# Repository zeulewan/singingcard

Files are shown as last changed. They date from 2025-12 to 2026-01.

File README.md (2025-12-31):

# KiCad Agent Experiment

An experiment to have Claude Code autonomously design and order PCBs from start to finish.

## Goal

Given project requirements (e.g., "make an ESP32 dev board with USB-C and 3 GPIO LEDs"), Claude Code should be able to:

1. Research and select appropriate components from JLCPCB's library
2. Design the schematic with proper connections
3. Create the PCB layout
4. Auto-route the traces
5. Run DRC/ERC checks
6. Generate fabrication files
7. Order the PCB via JLCPCB API

The human should only need to:
- Provide initial requirements
- Set up API keys
- Occasionally review/approve major decisions

## Status

**Setup Phase** - Installing tools and creating workflow documentation.

## Structure

```
singingcard/
├── kicad/              # KiCad project files
├── docs/               # Documentation and notes
├── venv/               # Python virtual environment
└── .claude/skills/     # Claude skill for KiCad workflow
```

## Tools

See `docs/tool-setup.md` for installed tools and configuration.

---

## Board Design

Export KiCad Images

<div align="center">
  <div>
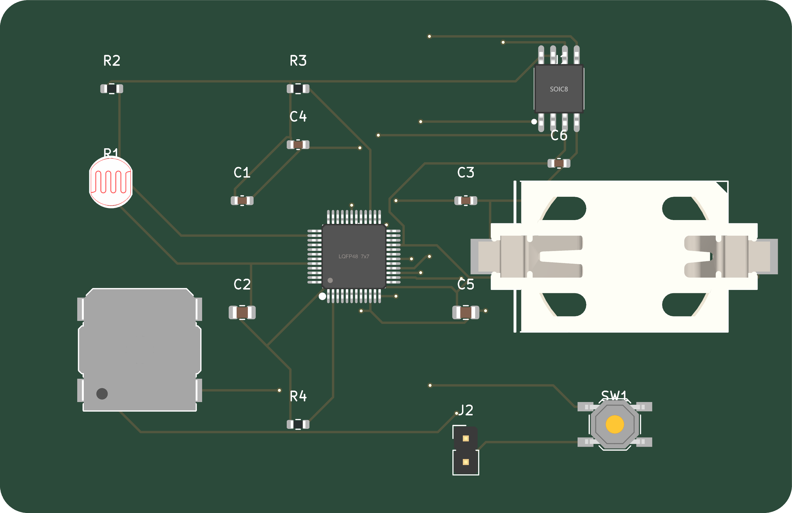
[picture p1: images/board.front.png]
3D Render Front
    
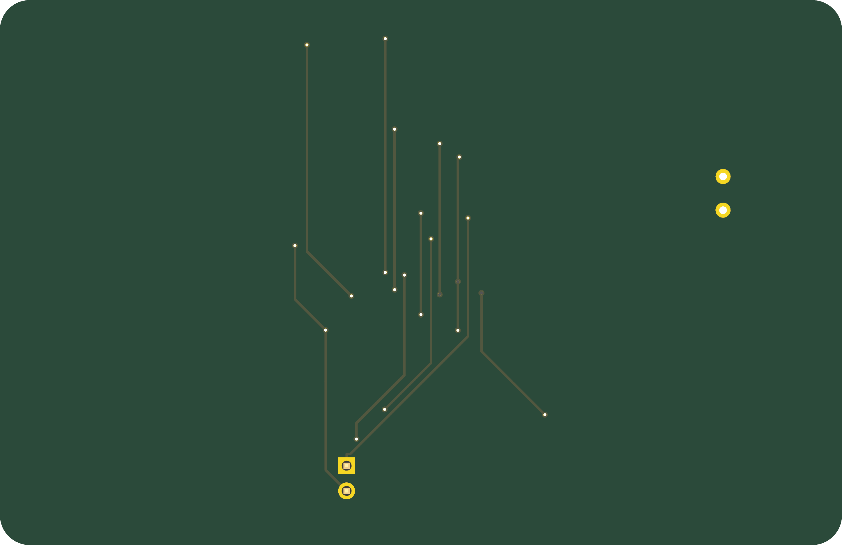
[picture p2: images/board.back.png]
3D Render Back
    
    <p><em>3D Render</em></p>
  </div>
  <br>

  <div>
    Schematic<br>
    <p><em>Schematic</em></p>
  </div>
  <br>

  <div>
    PCB Front
    PCB Back<br>
    <em>PCB Layout</em>
  </div>
</div>

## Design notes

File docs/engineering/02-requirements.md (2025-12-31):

# PCB Requirements Development

Phase 1 of PCB Systems Engineering Lifecycle.

## Activation
- User says: /pcb-requirements, develop requirements, conops
- After /pcb-init completes

## Purpose

Decompose PRD into detailed requirements and create Concept of Operations.

## Prerequisites

- `requirements/PRD.md` exists and is complete

## Process

### Step 1: Review PRD

Read `requirements/PRD.md` and extract:
- All stated requirements
- Implicit requirements (derived from use cases)
- Constraints and assumptions

### Step 2: Develop Operational Scenarios

Ask user about typical use cases:

**Question: User Profiles**
```
Who will use this device?
- End user (consumer)
- Technician (professional)
- Both
- Automated system (no direct user)
```

**Question: Primary Scenario**
```
Describe the most common way this device will be used:
1. How is it activated? (button, automatic, remote)
2. What happens during operation?
3. How long does typical operation last?
4. How is it deactivated?
```

**Question: Edge Cases**
```
What unusual situations might occur?
- Low battery
- Environmental extremes
- User errors
- Component failures
```

### Step 3: Create ConOps Document

Write `requirements/ConOps.md` with:

1. **System Overview** - One paragraph summary
2. **User Profiles** - Table of user types
3. **Operational Scenarios** - Step-by-step for each use case
4. **Operational Modes** - Normal, standby, error, etc.
5. **System States** - State machine if applicable
6. **Failure Modes** - What can go wrong, how detected

### Step 4: Decompose Requirements

Create detailed requirements in categories:

**Functional Requirements (FR-xxx)**
- What the system must DO
- Actions, behaviors, responses

**Performance Requirements (PR-xxx)**
- How WELL the system must perform
- Speed, accuracy, capacity, timing

**Interface Requirements (IR-xxx)**
- How system connects to external world
- Connectors, protocols, signals

**Environmental Requirements (ER-xxx)**
- Operating conditions
- Temperature, humidity, shock, vibration

**Physical Requirements (PHR-xxx)**
- Size, weight, form factor
- Mounting, enclosure

**Power Requirements (PWR-xxx)**
- Voltage, current, battery life
- Power states, consumption budgets

### Step 5: Assign Verification Methods

For each requirement, assign:
- **T** = Test (measure/observe in operation)
- **A** = Analysis (calculation/simulation)
- **I** = Inspection (visual examination)
- **D** = Demonstration (show it works)

### Step 6: Update RTM

Update `requirements/RTM.md` with all requirements:

```markdown
| ID | Requirement | Source | Verification | Status |
|----|-------------|--------|--------------|--------|
| FR-001 | System shall play audio | PRD 3.1 | T | Open |
| PR-001 | Audio shall be >70dB @ 10cm | PRD 4.1 | T | Open |
```

### Step 7: Output Summary

```
## Requirements Development Complete

### Statistics
- Functional Requirements: [count]
- Performance Requirements: [count]
- Interface Requirements: [count]
- Total Requirements: [count]

### Key Risks Identified
1. [risk 1]
2. [risk 2]

### Next Steps
1. Review ConOps at requirements/ConOps.md
2. Review RTM at requirements/RTM.md
3. Run /pcb-system-design to create ICD
```

## Requirement Writing Rules

Good requirements are:
- **Necessary** - Traceable to a need
- **Verifiable** - Can be tested/measured
- **Unambiguous** - Only one interpretation
- **Complete** - All conditions specified
- **Consistent** - No conflicts with other requirements
- **Atomic** - One requirement per statement

Bad: "The system should be fast"
Good: "The system shall respond within 100ms of trigger activation"

## Success Criteria

- [ ] ConOps document complete
- [ ] All requirements decomposed with IDs
- [ ] All requirements have verification method
- [ ] RTM populated
- [ ] User reviewed and approved

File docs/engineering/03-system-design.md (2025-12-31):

# PCB System Design

Phase 2 of PCB Systems Engineering Lifecycle.

## Activation
- User says: /pcb-system-design, system design, icd, block diagram
- After requirements are complete

## Purpose

Create system architecture, block diagram, and Interface Control Document.

## Prerequisites

- `requirements/PRD.md` complete
- `requirements/ConOps.md` complete
- Requirements decomposed with IDs

## Process

### Step 1: Create System Block Diagram

Identify major functional blocks from requirements:

**Common PCB Functional Blocks:**
- Power Management (input, regulation, distribution)
- Processing (MCU, DSP, FPGA)
- Memory (Flash, RAM, EEPROM)
- Sensors (analog, digital)
- Actuators (motors, speakers, LEDs)
- Communication (wired, wireless)
- User Interface (buttons, displays)
- Protection (ESD, overvoltage, reverse polarity)

**Block Diagram Elements:**
```
┌─────────────────────────────────────────────────────────┐
│                    SYSTEM BOUNDARY                       │
│                                                          │
│  ┌─────────┐     ┌─────────┐     ┌─────────┐           │
│  │  Power  │────►│   MCU   │────►│ Output  │           │
│  │ Supply  │     │         │     │         │           │
│  └─────────┘     └────┬────┘     └─────────┘           │
│                       │                                  │
│                  ┌────▼────┐                            │
│                  │ Memory  │                            │
│                  └─────────┘                            │
│                                                          │
└─────────────────────────────────────────────────────────┘
     ▲                 ▲                    │
     │                 │                    ▼
  [POWER]           [TRIGGER]           [OUTPUT]
  Battery           Button/Sensor       Speaker/LED
```

### Step 2: Define Interfaces

For each connection between blocks and external world:

**Interface Definition Table:**
| Interface ID | From | To | Type | Description |
|---|---|----|----|---|
| IF-001 | Battery | Power Supply | Power | 3V CR2032 |
| IF-002 | Power Supply | MCU | Power | 3.0V regulated |
| IF-003 | MCU | Flash | SPI | 4-wire SPI @ 10MHz |
| IF-004 | MCU | Speaker | Analog | PWM audio output |
| IF-005 | Button | MCU | Digital | Active-low input |

### Step 3: Create Interface Control Document

Write `requirements/ICD.md`:

```markdown
# Interface Control Document: [Project Name]

## Document Control
| Version | Date | Author | Changes |
|---------|------|--------|---------|
| 1.0 | [date] | [name] | Initial |

## 1. Scope
This document defines all interfaces for [Project Name].

## 2. External Interfaces

### 2.1 Power Interface (IF-001)
| Parameter | Value | Tolerance |
|-----------|-------|-----------|
| Connector | N/A (coin cell holder) | |
| Voltage | 3.0V | 2.0V - 3.3V |
| Current (peak) | [X] mA | |
| Current (avg) | [X] mA | |

### 2.2 User Interface - Trigger (IF-005)
| Parameter | Value |
|-----------|-------|
| Type | Mechanical switch / Light sensor / Pull-tab |
| Logic | Active [high/low] |
| Debounce | [X] ms in firmware |

### 2.3 Audio Output (IF-004)
| Parameter | Value |
|-----------|-------|
| Type | PWM / DAC |
| Frequency Range | [X] Hz - [Y] kHz |
| Output Level | [X] dBV |

## 3. Internal Interfaces

### 3.1 MCU to Flash Memory (IF-003)
| Signal | MCU Pin | Flash Pin | Description |
|--------|---------|-----------|-------------|
| SCK | [pin] | CLK | Clock |
| MOSI | [pin] | DI | Data In |
| MISO | [pin] | DO | Data Out |
| CS | [pin] | /CS | Chip Select |

**Protocol:** SPI Mode 0
**Clock Speed:** 10 MHz max
**Data Format:** MSB first

### 3.2 MCU to Power Supply (IF-002)
| Rail | Voltage | Current | Ripple |
|------|---------|---------|--------|
| VCC | 3.0V | [X] mA | < 50mV |

## 4. Interface Drawings
[Block diagram reference]
```

### Step 4: Allocate Requirements to Blocks

Map requirements to functional blocks:

| Requirement | Block | Notes |
|---|---|---|
| FR-001: Play audio | MCU, Flash, Speaker | Audio chain |
| FR-002: Trigger on button | MCU, Button | Input processing |
| PR-001: 5min battery life | Power, MCU | Power budget |

### Step 5: Create Budgets

**Power Budget:**
| Block | Mode | Current (mA) | Duty Cycle | Avg (mA) |
|---|---|---|---|---|
| MCU | Active | 10 | 10% | 1.0 |
| MCU | Sleep | 0.01 | 90% | 0.009 |
| Flash | Read | 15 | 5% | 0.75 |
| Flash | Standby | 0.001 | 95% | 0.001 |
| Speaker | On | 50 | 10% | 5.0 |
| **Total** | | | | **6.76** |

Battery capacity: 220mAh (CR2032)
Estimated life: 220 / 6.76 = **32.5 hours** active

**Mass Budget (if constrained):**
| Component | Mass (g) | Notes |
|---|---|---|
| PCB | 5.0 | 50x50mm FR4 |
| Battery | 3.0 | CR2032 |
| Components | 2.0 | Estimate |
| **Total** | **10.0** | |

**Cost Budget:**
| Category | Target | Allocated |
|---|---|---|
| PCB | $1.00 | |
| Components | $3.00 | |
| Assembly | $1.00 | |
| **Total** | **$5.00** | |

### Step 6: Risk Assessment

Identify technical risks:

| Risk | Probability | Impact | Mitigation |
|---|---|---|---|
| Battery life insufficient | Medium | High | Optimize sleep modes |
| Audio quality poor | Low | Medium | Use proper DAC/amp |
| Size exceeds constraint | Low | High | Component selection |

### Step 7: Prepare for SRR

Create SRR package `process/reviews/SRR.md`:

```markdown
# System Requirements Review

## Project: [Name]
## Date: [date]

## Review Items

### 1. Requirements Completeness
- [ ] All stakeholder needs captured in PRD
- [ ] All requirements have unique IDs
- [ ] All requirements are verifiable
- [ ] No conflicting requirements

### 2. ConOps Validation
- [ ] All operational scenarios documented
- [ ] Failure modes identified
- [ ] User profiles defined

### 3. Interface Definition
- [ ] All external interfaces defined
- [ ] All internal interfaces defined
- [ ] Signal levels and protocols specified

### 4. Budget Allocations
- [ ] Power budget complete
- [ ] Mass budget complete (if applicable)
- [ ] Cost budget complete

### 5. Risk Assessment
- [ ] Technical risks identified
- [ ] Mitigations defined

## Action Items
| # | Action | Owner | Due |
|---|--------|-------|-----|
| | | | |

## Decision
[ ] APPROVED - Proceed to component selection
[ ] CONDITIONAL - Complete actions first
[ ] NOT APPROVED - Major rework required

## Signatures
- Technical Lead: _________________ Date: _____
- Stakeholder: _________________ Date: _____
```

## Output Summary

```
## System Design Complete

### Deliverables
- System block diagram
- Interface Control Document (ICD.md)
- Power/Mass/Cost budgets
- Requirements allocation
- Risk register

### SRR Status
Ready for System Requirements Review

### Next Steps
1. Conduct SRR with stakeholder
2. Get approval to proceed
3. Run /pcb-components for component selection
```

## Success Criteria

- [ ] Block diagram created
- [ ] All interfaces defined in ICD
- [ ] Requirements allocated to blocks
- [ ] Budgets established
- [ ] Risks documented
- [ ] SRR package ready

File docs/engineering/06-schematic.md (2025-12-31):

# PCB Schematic Design

Phase 5 of PCB Systems Engineering Lifecycle.

## Activation
- User says: /pcb-schematic, create schematic, design schematic
- After PDR gate passes

## Purpose

Create KiCad schematic from component selection and requirements.

## Prerequisites

- PDR complete (component selection approved)
- BOM draft exists
- Datasheets available for key components

## Process

### Step 1: Gather Design Information

From datasheets, extract for each IC:
- Typical application circuit
- Required external components (caps, resistors)
- Power supply requirements
- Pin connections

### Step 2: Create/Verify Symbols

For each component:

**If symbol exists in KiCad library:**
- Verify pin count matches datasheet
- Verify pin names match datasheet
- Verify pin types (power, input, output, bidirectional)

**If custom symbol needed:**
Create using Python script or KiCad:

```python
# Symbol creation pattern
symbol = {
    'name': 'PART_NUMBER',
    'pins': [
        {'num': '1', 'name': 'VCC', 'type': 'power_in'},
        {'num': '2', 'name': 'GND', 'type': 'power_in'},
        # ... all pins from datasheet
    ]
}
```

Save to `kicad/libs/[project].kicad_sym`

### Step 3: Schematic Organization

Use hierarchical sheets for complex designs:

```
Main Sheet
├── Power Supply
├── Microcontroller
├── Audio Section
├── User Interface
└── Connectors
```

For simple designs (< 20 components), single sheet is fine.

### Step 4: Place Components

**Order of placement:**
1. Main IC (center of functional block)
2. Power input/output
3. Decoupling capacitors (near power pins)
4. External components (per application circuit)
5. Connectors

**Placement rules:**
- Group related components
- Signal flow left-to-right or top-to-bottom
- Keep power and ground clear
- Leave room for labels

### Step 5: Wire Connections

**Connection methods:**
1. **Direct wires** - For short, local connections
2. **Net labels** - For connections across the sheet
3. **Global labels** - For connections between sheets
4. **Power symbols** - For power rails (VCC, GND, +3V3)

**Net naming conventions:**
- Power rails: `+3V3`, `+5V`, `GND`, `VBAT`
- SPI: `SPI_MOSI`, `SPI_MISO`, `SPI_SCK`, `SPI_CS`
- I2C: `I2C_SDA`, `I2C_SCL`
- Audio: `AUDIO_OUT`, `SP+`, `SP-`
- General: `TRIGGER`, `STATUS_LED`

### Step 6: Add Required Elements

- [ ] Power input protection (TVS, polyfuse if needed)
- [ ] Decoupling capacitors (100nF per power pin, 10uF bulk)
- [ ] Pull-up/pull-down resistors where needed
- [ ] Test points for debugging
- [ ] Mounting holes (mechanical symbols)
- [ ] Fiducials (if needed for assembly)

### Step 7: Annotation

Run annotation to assign reference designators:
- Resistors: R1, R2, R3...
- Capacitors: C1, C2, C3...
- ICs: U1, U2...
- Connectors: J1, J2...
- Switches: SW1, SW2...
- LEDs: D1, D2... or LED1, LED2...
- Speakers: LS1, LS2...

### Step 8: Electrical Rules Check (ERC)

Run ERC and resolve all errors:

**Common ERC errors and fixes:**

| Error | Cause | Fix |
|---|---|-----|
| Unconnected pin | Pin not wired | Connect or mark "no connect" |
| Power pin not driven | No power source | Add power symbol |
| Conflicting outputs | Two outputs connected | Check design, add buffer |
| Input not driven | Floating input | Add pull-up/down or connect |

**Acceptable warnings:**
- Power flags on power input connectors
- Bidirectional pins connected to each other

### Step 9: Design Review Checklist

```markdown
### Schematic Review Checklist

**Power:**
- [ ] All power pins connected to appropriate rail
- [ ] Decoupling caps on every IC power pin
- [ ] Bulk capacitor at power input
- [ ] Power-on sequence correct (if multiple rails)

**Signals:**
- [ ] All signals have defined logic levels
- [ ] Pull-ups on open-drain outputs
- [ ] Series resistors on high-speed lines if needed
- [ ] ESD protection on external connections

**Mechanical:**
- [ ] Mounting holes included
- [ ] Connector pinouts match external devices
- [ ] Test points accessible

**Documentation:**
- [ ] All components have values
- [ ] All nets have meaningful names
- [ ] Title block filled in
- [ ] Revision number set
```

### Step 10: Export and Document

1. Export PDF: `kicad/output/[project]_schematic.pdf`
2. Export netlist for PCB
3. Save ERC report

### Step 11: Output Summary

```
## Schematic Design Complete

### Statistics
- Components: [count]
- Nets: [count]
- Sheets: [count]

### ERC Results
- Errors: 0
- Warnings: [count] (all reviewed)

### Files Created
- kicad/[project].kicad_sch
- kicad/output/[project]_schematic.pdf

### Next Steps
1. Review schematic PDF
2. Verify against datasheets
3. Run /pcb-layout to start PCB design
```

## KiCad Global Label Orientation Rules

**CRITICAL: Label orientation depends on `justify` property, not angle:**

| Wire Direction | Angle | Justify | Result |
|---|---|---|---|
| Left (←) | 180 | right | Text reads left-to-right |
| Right (→) | 0 | left | Text reads left-to-right |
| Up (↑) | 270 | left | Text reads bottom-to-top |
| Down (↓) | 90 | right | Text reads top-to-bottom |

**Rule:** Labels pointing left or down use `justify right`, others use `justify left`

## Common Application Circuits

### LDO Regulator (e.g., AMS1117)
```
VIN ─┬─[C1 10uF]─┬─ GND
     │           │
     └─[LDO]─────┴─ VOUT ─┬─[C2 10uF]─ GND
         │                 │
        GND               LOAD
```

### Flash Memory (SPI)
```
MCU                    FLASH
MOSI ──────────────── DI
MISO ──────────────── DO
SCK  ──────────────── CLK
CS   ──────────────── /CS
3V3  ──────┬───────── VCC, /WP, /HOLD
           └─[100nF]─ GND
```

### Audio Output
```
DAC_OUT ─[C 10uF]─┬─ SP+
                  │
                 [SPEAKER]
                  │
                  └─ SP- ─ GND (or diff output)
```

## Success Criteria

- [ ] All components placed and wired
- [ ] ERC passes with 0 errors
- [ ] All warnings reviewed and acceptable
- [ ] Schematic PDF exported
- [ ] Design matches datasheets
- [ ] User approved

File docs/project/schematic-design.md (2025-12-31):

# Schematic Design: Singing Birthday Card

## Block Diagram

```
                    +3V (CR2032)
                         │
                         ▼
┌─────────────────────────────────────────────────────────────┐
│                      ISD3900FYI                              │
│                                                              │
│  SPI Flash Interface          │    Speaker Output            │
│  ─────────────────            │    ─────────────             │
│  MOSI (pin 16) ◄──────────────┼──► W25Q16 DI (pin 5)        │
│  MISO (pin 13) ◄──────────────┼──► W25Q16 DO (pin 2)        │  SPK+ (pin 18) ──►┌────────┐
│  SCLK (pin 14) ◄──────────────┼──► W25Q16 CLK (pin 6)       │                    │ Speaker │
│  SSB  (pin 15) ◄──────────────┼──► W25Q16 /CS (pin 1)       │  SPK- (pin 20) ──►│  8Ω    │
│                               │                              │                    └────────┘
│  GPIO (Triggers)              │                              │
│  ─────────────────            │                              │
│  GPIO0 (pin 38) ◄────────────[R]── LDR (GL5528)             │
│  GPIO1 (pin 32) ◄────────────[SW]── Button (optional)        │
│  GPIO2 (pin 31) ◄────────────[J]── Pull-tab (optional)       │
│                               │                              │
│  Power                        │                              │
│  ─────                        │                              │
│  VCC  (pin 11) ◄──────────────┼── +3V                        │
│  VREG (pin 12) ── 1µF ── GND  │                              │
│  VSS  (pin 10) ◄──────────────┼── GND                        │
│  VCCA (pin 43) ◄──────────────┼── +3V (with 0.1µF to GND)    │
│  VSSA (pin 44) ◄──────────────┼── GND                        │
│                               │                              │
│  Clock (Internal oscillator used - no external crystal)      │
│  XTALIN (pin 36) ── NC or GND │                              │
│  XTALOUT (pin 35) ── NC       │                              │
│                               │                              │
└─────────────────────────────────────────────────────────────┘
```

## Pin Connections

### ISD3900FYI (U1) - 48-LQFP

| Pin | Name | Connection | Notes |
|-----|---|---|---|
| 1 | NC | - | |
| 2 | CSB | Pull-up 10k to VCC | SPI chip select (active low) |
| 3 | DI | SPI data in from MCU | Not used (playback only) |
| 4-7 | I2S/GPIO4-7 | NC | I2S not used |
| 8-9 | NC | - | |
| 10 | VSS | GND | Digital ground |
| 11 | VCC | +3V | Digital power |
| 12 | VREG | 1µF to GND | Internal regulator output |
| 13 | MISO | W25Q16 DO (pin 2) | Flash data out |
| 14 | SCLK | W25Q16 CLK (pin 6) | Flash clock |
| 15 | SSB | W25Q16 /CS (pin 1) | Flash chip select |
| 16 | MOSI | W25Q16 DI (pin 5) | Flash data in |
| 17 | VCCD_PWM | +3V | PWM power |
| 18 | SPK+ | Speaker + | Speaker output |
| 19 | VSSD_PWM | GND | PWM ground |
| 20 | SPK- | Speaker - | Speaker output |
| 21 | VCCD_PWM | +3V | PWM power (tied to pin 17) |
| 22-24 | NC | - | |
| 25 | INTB | NC or pull-up | Interrupt output |
| 26 | RDY/BSYB | NC or pull-up | Ready/busy output |
| 27 | RESET | Pull-up 10k to VCC | Active low reset |
| 28 | DO | NC | SPI data out (not used) |
| 29 | CLK | NC | SPI clock in (not used) |
| 30-32 | GPIO3-1 | Trigger inputs | GPIO1/2 for button/pull-tab |
| 33-34 | NC | - | |
| 35 | XTALOUT | NC | Using internal oscillator |
| 36 | XTALIN | NC or 80k to GND | Internal oscillator |
| 37 | NC | - | |
| 38 | GPIO0 | LDR voltage divider | Light sensor input |
| 39-40 | NC | - | |
| 41 | AUDOUT | NC | Line out (not used) |
| 42 | AUXOUT | NC | Aux out (not used) |
| 43 | VCCA | +3V (0.1µF to GND) | Analog power |
| 44 | VSSA | GND | Analog ground |
| 45 | ANAOUT/MIC- | NC | Not used |
| 46 | ANAIN/MIC+ | NC | Not used |
| 47 | AUXIN | NC | Not used |
| 48 | NC | - | |

### W25Q16JVSSIQ (U2) - SOIC-8

| Pin | Name | Connection |
|-----|---|---|
| 1 | /CS | ISD3900 SSB (pin 15) |
| 2 | DO | ISD3900 MISO (pin 13) |
| 3 | IO2 | Pull-up 10k to VCC (or NC) |
| 4 | GND | GND |
| 5 | DI | ISD3900 MOSI (pin 16) |
| 6 | CLK | ISD3900 SCLK (pin 14) |
| 7 | IO3 | Pull-up 10k to VCC (or NC) |
| 8 | VCC | +3V |

### CR2032 Battery Holder (B1)

| Pin | Connection |
|-----|---|
| + | +3V rail |
| - | GND |

### GL5528 LDR (R1)

Voltage divider configuration:
```
+3V ── [10k] ── GPIO0 (pin 38) ── [LDR] ── GND
```
When light hits LDR, resistance drops, voltage at GPIO0 rises.

### Speaker (LS1) - 8Ω 0.5W

| Connection | ISD3900 Pin |
|---|---|
| Speaker + | SPK+ (pin 18) |
| Speaker - | SPK- (pin 20) |

### Optional Tactile Switch (SW1)

```
GPIO1 (pin 32) ── [10k pull-up] ── +3V
           └──── [Switch] ──── GND
```

### Optional Pull-Tab Contact (J1)

```
GPIO2 (pin 31) ── [10k pull-up] ── +3V
           └──── [Tab contact] ── GND
```
When tab is inserted, contact is broken (high). When tab is pulled, contact closes (low → trigger).

## Decoupling Capacitors

| Location | Value | Notes |
|---|---|---|
| VCC (pin 11) | 0.1µF + 10µF | Close to pin |
| VREG (pin 12) | 1µF | Regulator output |
| VCCA (pin 43) | 0.1µF | Analog power |
| VCCD_PWM (pin 17,21) | 10µF | PWM power |
| W25Q16 VCC | 0.1µF | Close to pin |

## Power Budget

| Component | Current (typical) | Current (max) |
|---|---|---|
| ISD3900 (standby) | 1µA | - |
| ISD3900 (playback) | 30mA | 50mA |
| ISD3900 (speaker) | - | 150mA |
| W25Q16 (read) | 5mA | 15mA |
| **Total (playback)** | ~40mA | ~200mA |

CR2032 capacity: ~220mAh
Estimated playback time: ~5-10 hours continuous (but greeting cards are used briefly)

## Trigger Logic

The ISD3900 can be configured via SPI to trigger playback on GPIO edges:
- GPIO0: Rising edge (light detected)
- GPIO1: Falling edge (button pressed)
- GPIO2: Falling edge (tab pulled)

Jumper selection can be done by enabling/disabling the corresponding GPIO pull-ups or connections.

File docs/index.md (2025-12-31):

# PCB Engineering Process

A deterministic workflow for PCB development following NASA/DoD/IEEE systems engineering standards, adapted for small-batch manufacturing with JLCPCB.

---

## Quick Start

1. **[Engineering Process](engineering/index.md)** - Start with `00-MASTER.md`
2. Follow phases 01-10 in order
3. Complete review gates (SRR, PDR, CDR, PRR) before proceeding

---

## Documentation Structure

| Folder | Purpose |
|---|---|
| `engineering/` | Reusable process docs (phases, references) |
| `project/` | Project-specific docs (PRD, BOM, pin mapping) |

---

## Engineering Phases

| Phase | Document | Review Gate |
|---|---|---|
| 1 | [Init](engineering/01-init.md) | - |
| 2 | [Requirements](engineering/02-requirements.md) | - |
| 3 | [System Design](engineering/03-system-design.md) | **SRR** |
| 4 | [Components](engineering/04-components.md) | - |
| 5 | [Pin Allocation](engineering/05-pin-allocation.md) | **PDR** |
| 6 | [Schematic](engineering/06-schematic.md) | - |
| 7 | [Layout](engineering/07-layout.md) | **CDR** |
| 8 | [DFM](engineering/08-dfm.md) | - |
| 9 | [Manufacture](engineering/09-manufacture.md) | **PRR** |
| 10 | [Test](engineering/10-test.md) | - |

---

## Project: Singing Birthday Card

| Document | Description |
|---|---|
| [PRD](project/PRD.md) | Product requirements |
| [Component Selection](project/component-selection.md) | BOM with LCSC parts |
| [Pin Connections](project/PIN-CONNECTIONS.md) | Complete pin mapping |
| [Status](project/status.md) | Current project status |

---

## Tooling

- **KiCad 9.0.x** - EDA suite
- **kicad-cli** - Command-line automation
- **FreeRouting** - Auto-routing
- **JLCPCB** - PCB fabrication and assembly

See [KiCad Version Notes](engineering/references/KICAD-VERSION.md) for details.

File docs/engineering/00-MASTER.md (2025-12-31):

# PCB Engineering Master Process

The master orchestrator document for PCB development projects. Follow phases in order, completing review gates before proceeding.

**Standard:** NASA/DoD/IEEE systems engineering adapted for JLCPCB manufacturing.

---

## Phase Documents

| Phase | Document | Description | Gate |
|---|---|---|---|
| 1 | [`01-init.md`](01-init.md) | Project initialization, PRD | - |
| 2 | [`02-requirements.md`](02-requirements.md) | ConOps, requirements decomposition | - |
| 3 | [`03-system-design.md`](03-system-design.md) | Block diagram, ICD, budgets | **SRR** |
| 4 | [`04-components.md`](04-components.md) | JLCPCB parts research, BOM | - |
| 5 | [`05-pin-allocation.md`](05-pin-allocation.md) | Datasheet analysis, pin mapping | **PDR** |
| 6 | [`06-schematic.md`](06-schematic.md) | KiCad schematic design, ERC | - |
| 7 | [`07-layout.md`](07-layout.md) | PCB routing, DRC | **CDR** |
| 8 | [`08-dfm.md`](08-dfm.md) | Design for manufacturing review | - |
| 9 | [`09-manufacture.md`](09-manufacture.md) | Gerber export, JLCPCB order | **PRR** |
| 10 | [`10-test.md`](10-test.md) | Verification, acceptance | - |

---

## Reference Documents

| Document | Description |
|---|---|
| [`references/KICAD-VERSION.md`](references/KICAD-VERSION.md) | KiCad 9 formats, CLI commands |
| [`references/TOOLING-WISHLIST.md`](references/TOOLING-WISHLIST.md) | Desired automation tools |
| [`references/workflow-reference.md`](references/workflow-reference.md) | Quick command reference |
| [`references/tool-setup.md`](references/tool-setup.md) | Installed tools and versions |

---

## Tooling Requirements

| Tool | Version | Purpose |
|---|---|---|
| **KiCad** | 9.0.x | EDA suite (schematic, PCB, 3D) |
| **kicad-cli** | 9.0.x | Command-line automation |
| **Python** | 3.11+ | Scripting and automation |
| **FreeRouting** | 2.0.1 | Auto-routing (requires Java 21) |

**KiCad 9 Library Formats:**
- Symbols: `.kicad_sym` (single file, multiple symbols)
- Footprints: `.kicad_mod` files in `.pretty/` folders
- 3D Models: `.wrl`, `.step` in `.3dshapes/` folders

See [`references/KICAD-VERSION.md`](references/KICAD-VERSION.md) for details.

---

## 1. Lifecycle Overview

This process follows the **V-Model** approach with formal review gates. Each phase has defined entry/exit criteria, required artifacts, and a corresponding verification phase.

```
                    STAKEHOLDER NEEDS
                          │
         ┌────────────────┼────────────────┐
         │                │                │
    ┌────▼────┐      ┌────▼────┐      ┌────▼────┐
    │  PRD    │      │ ConOps  │      │  ICD    │
    │ Phase 0 │      │ Phase 1 │      │ Phase 2 │
    └────┬────┘      └────┬────┘      └────┬────┘
         │                │                │
         └────────────────┼────────────────┘
                          │
                     ▼ SRR Gate ▼
                          │
                    ┌─────▼─────┐
                    │ Component │
                    │ Selection │
                    │  Phase 3  │
                    └─────┬─────┘
                          │
                     ▼ PDR Gate ▼
                          │
              ┌───────────┴───────────┐
              │                       │
         ┌────▼────┐             ┌────▼────┐
         │Schematic│             │   PCB   │
         │ Design  │             │ Layout  │
         │ Phase 5 │             │ Phase 7 │
         └────┬────┘             └────┬────┘
              │                       │
              └───────────┬───────────┘
                          │
                     ▼ CDR Gate ▼
                          │
                    ┌─────▼─────┐
                    │    DFM    │
                    │  Review   │
                    │  Phase 8  │
                    └─────┬─────┘
                          │
                     ▼ PRR Gate ▼
                          │
                    ┌─────▼─────┐
                    │   Order   │
                    │   PCBA    │
                    │  Phase 10 │
                    └─────┬─────┘
                          │
                    ┌─────▼─────┐
                    │   Test    │
                    │ & Verify  │
                    │ Phase 11  │
                    └─────┴─────┘
```

---

## 2. Review Gates

### 2.1 System Requirements Review (SRR)
**Purpose:** Confirm all requirements are complete, consistent, and verifiable.

| Entry Criteria | Exit Criteria |
|---|---|
| PRD drafted | PRD approved by stakeholder |
| ConOps drafted | ConOps validated |
| Initial ICD drafted | Interfaces defined |
| | Requirements Traceability Matrix (RTM) started |

**Required Artifacts:**
- [ ] Product Requirements Document (PRD)
- [ ] Concept of Operations (ConOps)
- [ ] Interface Control Document (ICD)
- [ ] Mass/Power/Cost budgets (initial)
- [ ] Risk register (initial)

---

### 2.2 Preliminary Design Review (PDR)
**Purpose:** Validate component selection and preliminary architecture.

| Entry Criteria | Exit Criteria |
|---|---|
| SRR complete | All components identified |
| Component research done | JLCPCB compatibility verified |
| | Datasheets collected |
| | BOM drafted |

**Required Artifacts:**
- [ ] Component Selection Matrix
- [ ] JLCPCB Parts Library validation
- [ ] Preliminary BOM with LCSC part numbers
- [ ] Preliminary schematic block diagram
- [ ] Updated risk register

---

### 2.3 Critical Design Review (CDR)
**Purpose:** Freeze detailed design before manufacturing.

| Entry Criteria | Exit Criteria |
|---|---|
| PDR complete | Schematic complete, ERC clean |
| Schematic designed | PCB layout complete, DRC clean |
| PCB routed | All design rules met |
| | BOM finalized |

**Required Artifacts:**
- [ ] Complete schematic (PDF export)
- [ ] PCB layout (Gerber preview)
- [ ] Final BOM with all LCSC parts
- [ ] Design Rule Check report (0 errors)
- [ ] Electrical Rules Check report (0 errors)
- [ ] 3D model renders

---

### 2.4 Production Readiness Review (PRR)
**Purpose:** Confirm manufacturing files are correct and complete.

| Entry Criteria | Exit Criteria |
|---|---|
| CDR complete | Gerbers generated and verified |
| DFM review done | JLCPCB order quote reviewed |
| | Assembly files validated |

**Required Artifacts:**
- [ ] Gerber files (verified in viewer)
- [ ] Drill files
- [ ] Pick-and-place file (CPL)
- [ ] BOM in JLCPCB format
- [ ] JLCPCB order screenshot/quote

---

## 3. Phase Definitions

### Phase 0: Project Initiation
**Skill:** `/pcb-init`
**Duration:** 1 session

**Activities:**
1. Gather stakeholder needs through structured questions
2. Draft Product Requirements Document (PRD)
3. Establish project scope and constraints
4. Create project directory structure

**Questions to Ask:**
- What is the primary function of this device?
- What are the physical constraints (size, weight, enclosure)?
- What is the power source (battery type, voltage)?
- What interfaces are required (USB, I2C, SPI, etc.)?
- What is the target unit cost at volume?
- What quantity will be produced?
- What is the operating environment?
- Are there regulatory requirements (FCC, CE, UL)?

---

### Phase 1: Requirements Elicitation
**Skill:** `/pcb-requirements`
**Duration:** 1-2 sessions

**Activities:**
1. Decompose PRD into technical requirements
2. Create Concept of Operations (ConOps)
3. Define use cases and operational scenarios
4. Identify interfaces with external systems

**Deliverables:**
- ConOps document
- Functional requirements list
- Performance requirements list
- Environmental requirements list
- Interface requirements list

---

### Phase 2: System Definition
**Skill:** `/pcb-system-design`
**Duration:** 1 session

**Activities:**
1. Create system block diagram
2. Define internal interfaces (ICD)
3. Allocate requirements to subsystems
4. Establish mass/power/cost budgets

**Deliverables:**
- System block diagram
- Interface Control Document
- Requirements allocation matrix
- Budget allocations

---

### Phase 3: Component Research & Selection
**Skill:** `/pcb-components`
**Duration:** 1-3 sessions

**Activities:**
1. Research component options for each function
2. Verify JLCPCB/LCSC availability
3. Check stock levels and lead times
4. Download and analyze datasheets
5. Create component selection matrix

**JLCPCB Compatibility Checklist:**
- [ ] Part is in JLCPCB Parts Library (Basic/Extended)
- [ ] Footprint matches JLCPCB library or custom is allowed
- [ ] Stock level > order quantity + margin
- [ ] Package is SMD (for assembly) or THT marked accordingly
- [ ] Operating temperature range meets requirements

**Deliverables:**
- Component Selection Matrix
- Datasheets (saved to docs/datasheets/)
- Preliminary BOM with LCSC numbers
- Component risk assessment

---

### Phase 4: PDR Execution
**Skill:** `/pcb-pdr`
**Duration:** 1 session

**Activities:**
1. Present component selections
2. Review preliminary architecture
3. Identify remaining risks
4. Get stakeholder approval

**Deliverables:**
- PDR presentation/document
- Stakeholder sign-off
- Action items list

---

### Phase 5: Schematic Design
**Skill:** `/pcb-schematic`
**Duration:** 2-5 sessions

**Activities:**
1. Create/import component symbols
2. Place components and draw connections
3. Add power symbols and net labels
4. Run Electrical Rules Check (ERC)
5. Annotate and review

**Design Rules:**
- Use hierarchical sheets for complex designs
- Label all power rails with voltage
- Add test points for debugging
- Include decoupling capacitors per datasheet
- Add mounting holes and connectors

**Deliverables:**
- KiCad schematic (.kicad_sch)
- ERC report (0 errors, warnings reviewed)
- Schematic PDF export
- Net list

---

### Phase 6: CDR Preparation
**Skill:** `/pcb-cdr-prep`
**Duration:** 1 session

**Activities:**
1. Final schematic review
2. Preliminary PCB stackup decision
3. Critical component placement study
4. Thermal analysis (if needed)

---

### Phase 7: PCB Layout
**Skill:** `/pcb-layout`
**Duration:** 2-5 sessions

**Activities:**
1. Set board outline and mechanical constraints
2. Place components (critical first, then others)
3. Route traces (power first, then signals)
4. Add copper pours for ground/power
5. Run Design Rules Check (DRC)
6. Generate 3D model

**JLCPCB Design Rules (2-layer, 1oz copper):**
| Parameter | Minimum | Recommended |
|---|---|---|
| Trace width | 5 mil (0.127mm) | 6 mil (0.15mm) |
| Trace spacing | 5 mil (0.127mm) | 6 mil (0.15mm) |
| Via drill | 0.3mm | 0.3mm |
| Via pad | 0.6mm | 0.7mm |
| Via-to-trace | 5 mil | 6 mil |
| Hole-to-trace | 0.25mm | 0.3mm |
| Annular ring | 0.15mm | 0.2mm |

**Deliverables:**
- KiCad PCB (.kicad_pcb)
- DRC report (0 errors)
- 3D renders (front/back)
- Layer stackup document

---

### Phase 8: DFM Review
**Skill:** `/pcb-dfm`
**Duration:** 1 session

**Activities:**
1. Verify all JLCPCB design rules met
2. Check component orientations for assembly
3. Verify fiducials (if required)
4. Check silkscreen readability
5. Verify tooling holes (if panelized)

**DFM Checklist:**
- [ ] All traces meet minimum width/spacing
- [ ] All vias meet minimum drill/pad size
- [ ] Board outline is closed and on Edge.Cuts layer
- [ ] No copper-to-edge violations (<0.3mm)
- [ ] Silkscreen doesn't overlap pads
- [ ] All components have reference designators
- [ ] Fiducials present (for assembly)
- [ ] Polarity markings visible on silkscreen

---

### Phase 9: PRR Execution
**Skill:** `/pcb-prr`
**Duration:** 1 session

**Activities:**
1. Generate Gerbers using Fabrication Toolkit
2. Verify Gerbers in external viewer
3. Generate BOM and CPL files
4. Upload to JLCPCB for quote
5. Review DFM feedback from JLCPCB
6. Get stakeholder approval to order

**Deliverables:**
- Gerber ZIP file
- BOM CSV (JLCPCB format)
- CPL CSV (pick-and-place)
- JLCPCB quote screenshot
- Order confirmation

---

### Phase 10: Manufacturing
**Skill:** `/pcb-manufacture`
**Duration:** External (5-15 days)

**Activities:**
1. Submit order to JLCPCB
2. Monitor order status
3. Track shipping
4. Receive and inspect boards

**Quality Inspection Checklist:**
- [ ] Board dimensions match design
- [ ] Drill holes are correct size and location
- [ ] Copper traces are clean, no shorts/opens
- [ ] Solder mask is properly applied
- [ ] Silkscreen is readable
- [ ] Components are correctly placed
- [ ] Solder joints are acceptable
- [ ] No visible defects

---

### Phase 11: Test & Verification
**Skill:** `/pcb-test`
**Duration:** 1-3 sessions

**Activities:**
1. Visual inspection
2. Continuity testing
3. Power-on test (current limiting)
4. Functional testing per test plan
5. Document results

**Test Levels:**
1. **Unit Test:** Individual component verification
2. **Integration Test:** Subsystem interaction
3. **System Test:** Full device operation
4. **Acceptance Test:** Against requirements

**Deliverables:**
- Test report
- Verification matrix (requirements vs. test results)
- Defect log (if any)
- Lessons learned

---

## 4. Configuration Management

### 4.1 Baselines

| Baseline | Established At | Contents |
|---|---|---|
| Functional | SRR | PRD, ConOps, ICD |
| Allocated | PDR | Component list, BOM draft |
| Product | CDR | Schematic, PCB, final BOM |
| As-Built | PRR | Gerbers, manufacturing files |

### 4.2 Change Control

After each baseline is established, changes require:
1. Change request documented
2. Impact analysis performed
3. Stakeholder approval
4. Implementation and verification
5. Baseline update

### 4.3 Version Numbering

- **Documents:** `DOC-XXX_v1.0.pdf`
- **Schematics:** Revision field in title block
- **PCB:** Revision field in title block + silkscreen
- **BOM:** Version in filename `BOM_v1.0.csv`

---

## 5. Directory Structure Standard

```
project-name/
├── CLAUDE.md              # Project-specific AI instructions
├── README.md              # Project overview
├── .gitignore
│
├── docs/                  # Documentation learned
│   ├── research/          # Research notes, web findings
│   ├── datasheets/        # Component datasheets (PDF)
│   └── references/        # Standards, app notes
│
├── process/               # Systems engineering
│   ├── reviews/           # SRR, PDR, CDR, PRR documents
│   ├── baselines/         # Frozen configuration snapshots
│   └── skills/            # Phase-specific skill files
│
├── requirements/          # Requirements documents
│   ├── PRD.md             # Product Requirements Document
│   ├── ConOps.md          # Concept of Operations
│   ├── ICD.md             # Interface Control Document
│   └── RTM.md             # Requirements Traceability Matrix
│
├── kicad/                 # KiCad project files
│   ├── project.kicad_pro  # KiCad project
│   ├── project.kicad_sch  # Schematic
│   ├── project.kicad_pcb  # PCB layout
│   ├── libs/              # Custom libraries
│   │   ├── project.kicad_sym
│   │   └── project.pretty/
│   └── output/            # Generated files
│       ├── gerbers/
│       ├── bom/
│       └── images/
│
├── images/                # Auto-generated by GitHub Action
│   ├── sch.svg
│   ├── pcbf.svg
│   ├── pcbb.svg
│   └── board.step
│
├── tmp/                   # NOT TRACKED - temporary workspace
│   ├── latest_render.png  # Latest inspection image
│   └── notes.txt          # Scratch notes
│
└── firmware/              # If applicable
    └── src/
```

---

## 6. Required Documents

### 6.1 Product Requirements Document (PRD)

```markdown
# Product Requirements Document: [Project Name]

## 1. Purpose
[One paragraph describing what this product does]

## 2. Stakeholders
| Role | Name | Contact |
|------|------|---------|

## 3. Functional Requirements
| ID | Requirement | Priority | Verification |
|----|-------------|----------|--------------|
| FR-001 | | | |

## 4. Performance Requirements
| ID | Requirement | Value | Tolerance | Verification |
|----|-------------|-------|-----------|--------------|
| PR-001 | | | | |

## 5. Physical Requirements
| Parameter | Value | Notes |
|-----------|-------|-------|
| Dimensions | | |
| Weight | | |
| Enclosure | | |

## 6. Environmental Requirements
| Parameter | Min | Typ | Max |
|-----------|-----|-----|-----|
| Operating Temp | | | |
| Storage Temp | | | |
| Humidity | | | |

## 7. Power Requirements
| Parameter | Value | Notes |
|-----------|-------|-------|
| Source | | |
| Voltage | | |
| Current (avg) | | |
| Current (peak) | | |
| Battery Life | | |

## 8. Interface Requirements
| Interface | Type | Description |
|-----------|------|-------------|

## 9. Cost Targets
| Item | Target | Notes |
|------|--------|-------|
| Unit cost (1) | | |
| Unit cost (100) | | |
| Unit cost (1000) | | |

## 10. Schedule
| Milestone | Target Date |
|-----------|-------------|

## 11. Constraints
-
-

## 12. Assumptions
-
-
```

### 6.2 Concept of Operations (ConOps)

```markdown
# Concept of Operations: [Project Name]

## 1. System Overview
[Description of the system and its purpose]

## 2. User Profiles
| User Type | Description | Frequency of Use |
|-----------|-------------|------------------|

## 3. Operational Scenarios

### Scenario 1: [Name]
1. User action
2. System response
3. ...

### Scenario 2: [Name]
...

## 4. Operational Modes
| Mode | Description | Transitions |
|------|-------------|-------------|

## 5. System States
[State diagram or description]

## 6. Failure Modes
| Failure | Detection | Response |
|---------|-----------|----------|
```

### 6.3 Interface Control Document (ICD)

```markdown
# Interface Control Document: [Project Name]

## 1. External Interfaces

### 1.1 Power Interface
| Parameter | Value |
|-----------|-------|
| Connector | |
| Voltage | |
| Current | |

### 1.2 [Interface Name]
...

## 2. Internal Interfaces

### 2.1 [Subsystem A] to [Subsystem B]
| Signal | Direction | Type | Description |
|--------|-----------|------|-------------|
```

---

## 7. Skill Invocation Map

The master skill `/pcb-master` orchestrates all phases:

| Phase | Skill | Trigger Condition |
|---|---|---|
| 0 | `/pcb-init` | New project |
| 1 | `/pcb-requirements` | After PRD draft |
| 2 | `/pcb-system-design` | After ConOps |
| 3 | `/pcb-components` | After SRR |
| 4 | `/pcb-pdr` | Components selected |
| 5 | `/pcb-schematic` | After PDR |
| 6 | `/pcb-cdr-prep` | Schematic complete |
| 7 | `/pcb-layout` | After CDR prep |
| 8 | `/pcb-dfm` | Layout complete |
| 9 | `/pcb-prr` | DFM clean |
| 10 | `/pcb-manufacture` | After PRR |
| 11 | `/pcb-test` | Boards received |

---

## 8. JLCPCB Integration

### 8.1 Parts Library Categories

| Category | Description | Cost Impact |
|---|---|---|
| Basic | Standard parts, always in stock | Lowest |
| Extended | Specialty parts, usually in stock | +$3 fee |
| Consignment | Customer provides parts | Handling fee |

### 8.2 Assembly Constraints

- **Minimum component size:** 0201 (imperial)
- **Maximum component height:** 5mm (standard), 8mm (large)
- **Minimum pitch:** 0.4mm (BGA), 0.5mm (QFP)
- **Sides:** Top-only or top+bottom (extra cost)
- **Fiducials:** Required for fine-pitch (< 0.5mm)

### 8.3 File Format Requirements

**Gerbers:**
- Format: RS-274X
- Extension: Standard (e.g., `.gtl`, `.gbl`)
- Layers: F.Cu, B.Cu, F.Mask, B.Mask, F.Silkscreen, B.Silkscreen, Edge.Cuts

**Drill:**
- Format: Excellon
- Units: Metric (mm)

**BOM:**
- Format: CSV
- Columns: Designator, Footprint, Quantity, Value, LCSC Part #

**CPL:**
- Format: CSV
- Columns: Designator, Mid X, Mid Y, Rotation, Layer

---

## 9. Claude Code Limitations & Workarounds

| Limitation | Workaround |
|---|---|
| Cannot open KiCad GUI | Generate scripts, user executes in KiCad |
| Fabrication Toolkit requires GUI | User runs in KiCad, or use kicad-cli |
| Cannot view images directly | Export to tmp/, user confirms |
| DSN export not in kicad-cli | Use KiCad's Python with pcbnew module |
| FreeRouting requires Java 21 | Install via homebrew, specify path |
| Cannot upload to JLCPCB | Generate files, user uploads |

---

## 10. References

- NASA Systems Engineering Handbook (NASA/SP-2016-6105)
- NASA Procedural Requirements NPR 7123.1
- DoD Instruction 5000.88 - Engineering of Defense Systems
- IEEE 1220-2005 - Systems Engineering
- ISO/IEC/IEEE 29148:2018 - Requirements Engineering
- JLCPCB Capabilities: https://jlcpcb.com/capabilities/pcb-capabilities

---

## Appendix A: Checklists

### A.1 SRR Checklist
- [ ] PRD complete with all sections
- [ ] All requirements have unique IDs
- [ ] All requirements are verifiable
- [ ] ConOps reviewed by stakeholder
- [ ] Interfaces identified
- [ ] Risks documented

### A.2 PDR Checklist
- [ ] All functions have component selections
- [ ] All parts verified in JLCPCB library
- [ ] Datasheets downloaded and reviewed
- [ ] BOM draft with LCSC numbers
- [ ] Block diagram complete
- [ ] Risks updated

### A.3 CDR Checklist
- [ ] Schematic complete
- [ ] ERC passes with 0 errors
- [ ] PCB layout complete
- [ ] DRC passes with 0 errors
- [ ] BOM finalized
- [ ] 3D model reviewed

### A.4 PRR Checklist
- [ ] Gerbers generated
- [ ] Gerbers verified in external viewer
- [ ] BOM in JLCPCB format
- [ ] CPL in JLCPCB format
- [ ] JLCPCB quote reviewed
- [ ] Stakeholder approval obtained

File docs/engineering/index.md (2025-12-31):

# Engineering Process

Phase-based PCB development following NASA/DoD/IEEE standards.

See [00-MASTER.md](00-MASTER.md) to get started.

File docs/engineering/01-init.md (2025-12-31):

# PCB Project Initialization

Phase 0 of PCB Systems Engineering Lifecycle.

## Activation
- User says: /pcb-init, start new pcb, new pcb project, init pcb
- First phase of /pcb-master workflow

## Purpose

Gather stakeholder needs and create Product Requirements Document (PRD).

## Process

### Step 1: Project Identification

Ask the user:
```
What is the name of this project?
```

### Step 2: Structured Requirements Gathering

Use AskUserQuestion to gather requirements systematically:

**Question Set 1: Core Function**
```
What is the PRIMARY function of this device?
- Audio playback (speaker, buzzer, music)
- Sensing (temperature, light, motion, etc.)
- Control (motor, relay, LED)
- Communication (wireless, wired)
- Power management (charging, regulation)
- Other: [describe]
```

**Question Set 2: Power Source**
```
How will this device be powered?
- CR2032 coin cell (3V, ~220mAh)
- CR2025 coin cell (3V, ~160mAh)
- AAA batteries (1.5V each)
- AA batteries (1.5V each)
- LiPo battery (3.7V rechargeable)
- USB powered (5V)
- Mains powered (with transformer)
- Other: [specify]
```

**Question Set 3: Physical Constraints**
```
What are the size constraints?
- Credit card size (~85x54mm)
- Business card size (~90x55mm)
- Compact (~50x50mm or smaller)
- No constraints
- Custom: [specify dimensions]
```

**Question Set 4: Quantity & Cost**
```
What quantity will be produced?
- Prototype only (1-5 units)
- Small batch (10-50 units)
- Medium batch (100-500 units)
- Production (1000+ units)

What is the target unit cost?
- Under $5
- $5-15
- $15-50
- Over $50
- No constraint
```

**Question Set 5: Interfaces**
```
What interfaces are required? (Select all that apply)
- [ ] USB (charging or data)
- [ ] Audio output (speaker/headphones)
- [ ] Audio input (microphone)
- [ ] Display (LED, LCD, OLED)
- [ ] Buttons/switches
- [ ] Sensors (specify type)
- [ ] Wireless (WiFi, Bluetooth, LoRa)
- [ ] Programming/debug port
- [ ] Other: [specify]
```

**Question Set 6: Environment**
```
What is the operating environment?
- Indoor, room temperature only
- Indoor, wide temperature range
- Outdoor, weather protected
- Outdoor, fully exposed
- Other: [specify]
```

**Question Set 7: Special Requirements**
```
Any special requirements?
- [ ] Low power / battery life critical
- [ ] Small size critical
- [ ] Low cost critical
- [ ] Fast time to market
- [ ] Regulatory compliance (FCC, CE)
- [ ] Safety critical
- [ ] None
```

### Step 3: Create Directory Structure

```bash
mkdir -p requirements docs/{research,datasheets,references} \
         process/{reviews,baselines} kicad/{libs,output} tmp
```

### Step 4: Generate PRD

Create `requirements/PRD.md` using the template from PCB-SYSTEMS-ENGINEERING.md, filling in gathered information.

### Step 5: Output Summary

```
## Project Initialized: [Project Name]

### Key Requirements
- Function: [primary function]
- Power: [power source]
- Size: [dimensions]
- Quantity: [volume]
- Cost Target: [target]

### Next Steps
1. Review the PRD at requirements/PRD.md
2. Edit any incorrect information
3. Run /pcb-requirements to develop ConOps

### Files Created
- requirements/PRD.md
- requirements/ConOps.md (template)
- requirements/ICD.md (template)
- requirements/RTM.md (template)
```

## Templates to Create

### PRD.md Template
Fill in the template from PCB-SYSTEMS-ENGINEERING.md Section 6.1

### ConOps.md Template (Empty)
Fill in the template from PCB-SYSTEMS-ENGINEERING.md Section 6.2

### ICD.md Template (Empty)
Fill in the template from PCB-SYSTEMS-ENGINEERING.md Section 6.3

### RTM.md Template
```markdown
# Requirements Traceability Matrix

| Req ID | Requirement | Source | Allocated To | Verification | Status |
|--------|-------------|--------|--------------|--------------|--------|
| FR-001 | | PRD | | | Open |
```

## Success Criteria

- [ ] All key questions answered
- [ ] PRD created with all sections
- [ ] Directory structure in place
- [ ] User understands next steps

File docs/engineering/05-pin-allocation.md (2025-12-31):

# PCB Pin Allocation & Datasheet Analysis

Phase 3.5 of PCB Systems Engineering Lifecycle - between component selection and schematic design.

## Activation
- User says: /pcb-pin-allocation, pin allocation, datasheet analysis, chip research
- After component selection, before schematic design

## Purpose

Thoroughly analyze all component datasheets and create a complete pin connection map before starting schematic design.

## Prerequisites

- Component selection complete (BOM exists)
- LCSC/JLCPCB part numbers identified

## Critical Rules

**DO NOT start schematic design until this phase is complete.**

1. **Read EVERY datasheet** - No exceptions
2. **Understand EVERY pin** - Know what each pin does
3. **Document EVERY connection** - In PIN-CONNECTIONS.md
4. **NEVER GUESS** - Each pin function MUST come from the datasheet

**If you cannot access a datasheet, you CANNOT proceed with that component.**

KiCad symbols are NOT authoritative - they may have errors or be incomplete. The datasheet is the single source of truth.

## Process

### Step 1: Create Datasheets Directory

```bash
mkdir -p docs/datasheets
```

### Step 2: Download All Datasheets

For each component in BOM:

1. **ICs (Critical):** Download full datasheet from manufacturer
2. **Passives:** Note values, tolerances, voltage ratings
3. **Connectors:** Download mechanical drawings
4. **Specialty:** Sensors, speakers, displays - full datasheets

**Datasheet Sources:**
- LCSC product page → Datasheet link
- Manufacturer website (preferred - most current)
- Octopart/Findchips for alternatives

**Naming Convention:**
```
docs/datasheets/
├── ISD3900_datasheet.pdf
├── W25Q16JV_datasheet.pdf
├── AMS1117-3.3_datasheet.pdf
├── KLJ-01304T_speaker_datasheet.pdf
└── GL5528_LDR_datasheet.pdf
```

### Step 3: Read Each Datasheet - Extract Key Information

For each IC, document:

#### 3.1 Power Requirements
```markdown
## [Part Number] Power

| Parameter | Min | Typ | Max | Unit |
|-----------|-----|-----|-----|------|
| VCC | 2.7 | 3.0 | 3.6 | V |
| ICC (active) | - | 15 | 25 | mA |
| ICC (standby) | - | 1 | 5 | µA |

**Power Pins:**
- VCC: pins 5, 17, 28
- GND: pins 6, 18, 29
- AVCC (analog): pin 12

**Decoupling Required:**
- 100nF on each VCC/GND pair
- 10µF bulk on main supply
```

#### 3.2 Pin Functions
```markdown
## [Part Number] Pin Functions

| Pin | Name | Type | Description |
|-----|------|------|-------------|
| 1 | RESET | Input | Active low reset |
| 2 | XTAL1 | Input | Crystal input |
| 3 | XTAL2 | Output | Crystal output |
| ... | ... | ... | ... |

**Pin Types:**
- Power: VCC, GND, AVCC, AGND
- Input: Digital input, analog input
- Output: Digital output, open-drain, push-pull
- I/O: Bidirectional
- NC: No connect (leave floating or tie to GND per datasheet)
```

#### 3.3 Interface Requirements
```markdown
## [Part Number] Interfaces

### SPI Interface
| Signal | Pin | Notes |
|--------|-----|-------|
| MOSI | 15 | Master Out, Slave In |
| MISO | 16 | Master In, Slave Out |
| SCK | 17 | Clock, max 10MHz |
| CS | 18 | Active low chip select |

**SPI Mode:** Mode 0 (CPOL=0, CPHA=0)
**Max Clock:** 10 MHz
**Bit Order:** MSB first

### I2C Interface
| Signal | Pin | Notes |
|--------|-----|-------|
| SDA | 20 | Needs 4.7k pull-up |
| SCL | 21 | Needs 4.7k pull-up |

**Address:** 0x50 (7-bit)
**Max Clock:** 400 kHz
```

#### 3.4 Application Circuit
```markdown
## [Part Number] Application Circuit

From datasheet Figure X, page Y:

**Required External Components:**
- C1: 100nF ceramic, VCC to GND
- C2: 10µF electrolytic, VCC to GND
- R1: 10k pull-up on RESET
- Y1: 12MHz crystal
- C3, C4: 22pF load capacitors for crystal

**Optional Components:**
- LED on status pin (with 330R series)
- External EEPROM on I2C bus
```

#### 3.5 Absolute Maximum Ratings
```markdown
## [Part Number] Absolute Maximums

| Parameter | Value | Notes |
|-----------|-------|-------|
| VCC | 4.0V | Destroy above this |
| Input voltage | VCC + 0.5V | ESD clamp |
| Output current | 25mA | Per pin |
| Total power | 500mW | With derating |
| Storage temp | -40 to +85°C | |
```

### Step 4: Create Pin Connection Matrix

Create `docs/PIN-CONNECTIONS.md`:

```markdown
# Pin Connections

## System Overview

[Block diagram of connections]

## Net List

| Net Name | Source | Destination(s) | Notes |
|----------|--------|----------------|-------|
| +3V3 | U3.OUT | U1.VCC, U2.VCC, C1+ | Main 3.3V rail |
| GND | Battery- | All GND pins | Star ground |
| SPI_MOSI | U1.MOSI | U2.DI | SPI data out |
| SPI_MISO | U2.DO | U1.MISO | SPI data in |
| SPI_SCK | U1.SCK | U2.CLK | SPI clock |
| SPI_CS | U1.GPIO5 | U2./CS | Chip select |

## Component Pin Assignments

### U1: [Main IC]

| Pin | Name | Net | Connection | Notes |
|-----|------|-----|------------|-------|
| 1 | VCC | +3V3 | Power rail | 100nF to GND |
| 2 | GND | GND | Ground | |
| 3 | MOSI | SPI_MOSI | U2.DI | |
| 4 | MISO | SPI_MISO | U2.DO | |
| ... | ... | ... | ... | ... |

### U2: [Flash Memory]

| Pin | Name | Net | Connection | Notes |
|-----|------|-----|------------|-------|
| 1 | /CS | SPI_CS | U1.GPIO5 | Active low |
| 2 | DO | SPI_MISO | U1.MISO | |
| 3 | /WP | +3V3 | Pull high | Disable write protect |
| 4 | GND | GND | Ground | |
| 5 | DI | SPI_MOSI | U1.MOSI | |
| 6 | CLK | SPI_SCK | U1.SCK | |
| 7 | /HOLD | +3V3 | Pull high | Disable hold |
| 8 | VCC | +3V3 | Power | 100nF to GND |

### Passive Components

| Ref | Value | Net 1 | Net 2 | Purpose |
|-----|-------|-------|-------|---------|
| C1 | 100nF | +3V3 | GND | U1 decoupling |
| C2 | 100nF | +3V3 | GND | U2 decoupling |
| C3 | 10µF | +3V3 | GND | Bulk capacitor |
| R1 | 10k | TRIGGER | GND | Pull-down |

## Power Distribution

```
Battery (+3V)
    │
    ├──[Polarity Protection]──┬── VCC_RAW
    │                         │
    │                    [LDO 3.3V]
    │                         │
    │                         ├── +3V3
    │                         │    ├── U1.VCC (100nF)
    │                         │    ├── U2.VCC (100nF)
    │                         │    └── 10µF bulk
    │                         │
    └─────────────────────────┴── GND
```

## Signal Routing Priority

1. **Power:** Wide traces, short paths
2. **Clock/Crystal:** Short, away from noisy signals
3. **SPI:** Keep together, matched lengths if >10MHz
4. **Audio:** Away from digital, ground shield if possible
5. **GPIO:** Flexible routing

## Open Questions

- [ ] Does U1 need external crystal or internal oscillator OK?
- [ ] What pull-up value for I2C? (Depends on bus capacitance)
- [ ] Speaker connection: single-ended or differential?
```

### Step 5: Verify Completeness

Checklist before proceeding to schematic:

```markdown
## Pre-Schematic Checklist

### Datasheets Downloaded
- [ ] U1: [part] - datasheet.pdf
- [ ] U2: [part] - datasheet.pdf
- [ ] All ICs have datasheets

### Power Analysis
- [ ] All power pins identified
- [ ] Current budget calculated
- [ ] Decoupling requirements noted

### Pin Allocation
- [ ] All IC pins have assignments
- [ ] No pin conflicts
- [ ] All interfaces defined

### External Components
- [ ] All required passives identified
- [ ] Values match datasheet recommendations
- [ ] Voltage ratings adequate

### Questions Resolved
- [ ] All "Open Questions" answered
- [ ] Ambiguities clarified with datasheets or research
```

## Output

After completing this phase:

```
docs/
├── datasheets/
│   ├── ISD3900_datasheet.pdf
│   ├── W25Q16JV_datasheet.pdf
│   └── ...
├── PIN-CONNECTIONS.md      # Complete pin map
└── research/
    └── chip-notes.md       # Detailed notes from datasheets
```

## Datasheet Sources and Fallbacks

**Primary Sources (in order):**
1. Manufacturer website (most current, most reliable)
2. LCSC product page → Datasheet link
3. Octopart/Findchips
4. Mouser/DigiKey product pages

**Cross-Reference: KiCad Symbol Files**
After reading datasheets, verify KiCad symbols match:
- `kicad/libs/*.kicad_sym` - Compare pin names/numbers against datasheet
- Flag any discrepancies for correction

```bash
# List pin definitions from symbol file for verification
grep -A2 "pin " kicad/libs/project.kicad_sym
```

**If Datasheet Unavailable:**
- Try alternative sources (Mouser, DigiKey, Octopart)
- Contact manufacturer directly
- **DO NOT proceed with component if datasheet cannot be obtained**
- Consider selecting an alternative component with available documentation

**Web Fetch Limitations:**
- Some manufacturer sites block automated downloads
- Chinese datasheets may have encoding issues
- Large PDFs may timeout
- Solution: Have user manually download and place in `docs/datasheets/`

## Common Mistakes to Avoid

1. **Skipping datasheet reading** - "I'll figure it out in schematic" → errors
2. **Ignoring NC pins** - Some must be grounded, some must float
3. **Missing decoupling** - Every IC power pin needs capacitor
4. **Wrong pull-up/down** - Check if internal exists, correct value
5. **Voltage level mismatch** - 3.3V IC connected to 5V signal
6. **Forgetting analog ground** - AGND vs DGND separation

## Success Criteria

- [ ] All datasheets downloaded
- [ ] All datasheets read and understood
- [ ] PIN-CONNECTIONS.md complete
- [ ] All pins assigned
- [ ] No conflicts or ambiguities
- [ ] Ready for schematic design

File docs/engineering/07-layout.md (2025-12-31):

# PCB Layout Design

Phase 7 of PCB Systems Engineering Lifecycle.

## Activation
- User says: /pcb-layout, route pcb, pcb design, layout
- After schematic is complete

## Purpose

Create PCB layout from schematic with proper routing for JLCPCB manufacturing.

## Prerequisites

- Schematic complete with ERC clean
- Netlist generated
- Footprints assigned to all components

## JLCPCB Design Rules

### 2-Layer Board (1oz Copper) - Standard

| Parameter | Minimum | Recommended |
|---|---|---|
| Trace width | 0.127mm (5mil) | 0.15mm (6mil) |
| Trace spacing | 0.127mm (5mil) | 0.15mm (6mil) |
| Via drill | 0.3mm | 0.3mm |
| Via pad | 0.6mm | 0.7mm |
| Via-to-trace | 0.127mm (5mil) | 0.15mm (6mil) |
| Hole-to-trace | 0.25mm | 0.3mm |
| Hole-to-hole | 0.25mm | 0.3mm |
| Annular ring | 0.15mm | 0.2mm |
| Copper-to-edge | 0.3mm | 0.5mm |
| Silkscreen width | 0.15mm | 0.2mm |
| Silkscreen height | 0.8mm | 1.0mm |

### 4-Layer Board (1oz Copper)

| Parameter | Minimum | Recommended |
|---|---|---|
| Trace width | 0.09mm (3.5mil) | 0.1mm (4mil) |
| Trace spacing | 0.09mm (3.5mil) | 0.1mm (4mil) |
| Via drill | 0.2mm | 0.25mm |
| Via pad | 0.45mm | 0.5mm |

## Process

### Step 1: Board Setup

1. **Set board outline:**
   - Draw on Edge.Cuts layer
   - Closed polygon required
   - Consider mounting holes in corners
   - Consider enclosure fit

2. **Set design rules:**
   - File → Board Setup → Design Rules
   - Set clearance, track width, via size per JLCPCB specs
   - Add net classes for power (wider traces)

3. **Set stackup (if multilayer):**
   - File → Board Setup → Board Stackup
   - Standard 4-layer: Sig-GND-VCC-Sig

### Step 2: Component Placement

**Placement order:**
1. **Fixed items first:**
   - Connectors (USB, headers)
   - Mounting holes
   - Components with mechanical constraints

2. **Critical components:**
   - Main IC
   - Crystal/oscillator near IC
   - Decoupling caps near power pins

3. **Thermal considerations:**
   - High-power components away from edges
   - Heat-generating parts with clearance

4. **Signal flow:**
   - Input on one side, output on other
   - Minimize trace lengths

**Placement rules:**
- Keep related components close
- Align components in grid pattern
- Orient ICs consistently (pin 1 direction)
- Ensure reference designators visible
- Leave room for routing

### Step 3: Power Distribution

1. **Power planes or pours:**
   - 4-layer: Use internal layers for VCC/GND
   - 2-layer: Use copper pours on both layers

2. **Power trace sizing:**
   - Use net classes for power rails
   - Calculate trace width for current:
     - 1A @ 1oz: ~0.5mm trace (internal), ~0.3mm (external)
     - See IPC-2221 calculator

3. **Ground strategy:**
   - Single ground plane preferred
   - Star ground for analog/digital split
   - Avoid ground loops

### Step 4: Signal Routing

**Routing priority:**
1. Critical signals (clocks, high-speed)
2. Analog signals
3. Digital signals
4. Power connections

**Routing rules:**
- Avoid 90° angles (use 45° or curves)
- Match lengths for differential pairs
- Keep analog away from digital
- Cross signals at 90° on different layers
- Use vias to switch layers

**Routing strategies:**
- **Interactive routing:** Manual, highest control
- **Push-and-shove:** KiCad's smart routing
- **Autorouter:** FreeRouting for assistance

### Step 5: Autorouting (Optional)

**Using FreeRouting:**

1. Export DSN from KiCad:
```python
# Via KiCad Python console
import pcbnew
board = pcbnew.LoadBoard("project.kicad_pcb")
pcbnew.ExportSpecctraDSN(board, "project.dsn")
```

2. Run FreeRouting:
```bash
/opt/homebrew/opt/openjdk@21/bin/java -jar freerouting.jar
```

3. Import SES back:
```python
pcbnew.ImportSpecctraSES(board, "project.ses")
pcbnew.SaveBoard("project.kicad_pcb", board)
```

**Note:** Manual cleanup usually required after autorouting.

### Step 6: Copper Pours

1. **Add ground pour:**
   - Select both layers for 2-layer
   - Set net to GND
   - Set clearance per design rules
   - Use solid fill (not hatched)

2. **Add power pour (if needed):**
   - Typically smaller area
   - Connect to power traces

3. **Fill zones:**
   - Edit → Fill All Zones (B)
   - Check for isolated copper islands
   - Remove islands or add stitching vias

### Step 7: Silkscreen

- [ ] Reference designators visible and not overlapping pads
- [ ] Pin 1/polarity markings visible
- [ ] Board name and revision
- [ ] Date or version indicator
- [ ] Company/project logo (optional)
- [ ] Important warnings (ESD, polarity)

### Step 8: Design Rules Check (DRC)

Run DRC and fix all errors:

| Error | Cause | Fix |
|---|---|-----|
| Clearance violation | Traces too close | Reroute with more space |
| Track too thin | Below minimum | Widen trace |
| Unconnected net | Missing connection | Route or via |
| Annular ring too small | Via too small | Increase pad size |
| Copper-to-edge | Too close to board edge | Move copper in |

**DRC must show 0 errors before proceeding.**

### Step 9: 3D Model Review

1. View 3D model: View → 3D Viewer
2. Check:
   - [ ] Components fit without overlap
   - [ ] Correct component heights
   - [ ] Connectors accessible
   - [ ] Mounting holes clear
3. Export renders to `tmp/` for inspection

### Step 10: Output Summary

```
## PCB Layout Complete

### Board Statistics
- Size: [X] x [Y] mm
- Layers: [count]
- Components: [count]
- Vias: [count]
- Traces: [length]

### DRC Results
- Errors: 0
- Warnings: [count] (all reviewed)
- Unconnected nets: 0

### Files Updated
- kicad/[project].kicad_pcb

### Next Steps
1. Review 3D model in tmp/
2. Run /pcb-dfm for manufacturing check
```

## Layer Usage (2-Layer)

| Layer | Purpose |
|---|---|
| F.Cu | Top copper - most routing |
| B.Cu | Bottom copper - ground pour, some routing |
| F.Silkscreen | Top silkscreen - designators, labels |
| B.Silkscreen | Bottom silkscreen - if needed |
| F.Mask | Top solder mask (auto) |
| B.Mask | Bottom solder mask (auto) |
| F.Paste | Top solder paste (auto) |
| B.Paste | Bottom solder paste (auto) |
| Edge.Cuts | Board outline |
| F.Courtyard | Component keepout |
| F.Fab | Fabrication notes |

## Common Mistakes

1. **Forgetting decoupling caps near IC**
   - Place 100nF within 3mm of power pins

2. **Traces too close to edge**
   - Minimum 0.3mm, prefer 0.5mm

3. **Silkscreen on pads**
   - Enable "Subtract soldermask from silkscreen"

4. **Floating copper**
   - Connect or remove isolated copper islands

5. **Via under component**
   - Avoid unless needed for thermal

## Success Criteria

- [ ] All nets routed (0 unconnected)
- [ ] DRC passes with 0 errors
- [ ] 3D model reviewed
- [ ] Component placement verified
- [ ] Silkscreen readable
- [ ] Ground pour complete

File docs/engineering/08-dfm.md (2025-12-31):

# PCB Design for Manufacturing Review

Phase 8 of PCB Systems Engineering Lifecycle.

## Activation
- User says: /pcb-dfm, dfm check, manufacturing review
- After PCB layout complete

## Purpose

Verify PCB design meets JLCPCB manufacturing requirements before generating production files.

## Prerequisites

- PCB layout complete
- DRC passes with 0 errors
- 3D model reviewed

## DFM Checklist

### 1. Board Dimensions

- [ ] Board outline is closed polygon on Edge.Cuts
- [ ] Minimum size: 5mm x 5mm
- [ ] Maximum size: 400mm x 500mm
- [ ] No internal cutouts violate minimum rules
- [ ] Corners have appropriate radius (if required)

### 2. Copper Layers

**Trace Width & Spacing:**

| Copper | Min Width | Min Spacing | Status |
|---|---|---|---|
| 1oz external | 5mil (0.127mm) | 5mil (0.127mm) | [ ] |
| 1oz internal | 3.5mil (0.09mm) | 3.5mil (0.09mm) | [ ] |
| 2oz external | 8mil (0.2mm) | 8mil (0.2mm) | [ ] |

**Copper Pour:**
- [ ] No isolated copper islands (or intentionally left)
- [ ] Thermal relief on pads (not direct connect unless intended)
- [ ] Pour clearance meets minimum spacing

**Copper-to-Edge:**
- [ ] Minimum 0.3mm from copper to board edge
- [ ] V-score lines have appropriate copper clearance

### 3. Drill/Via

| Parameter | Min Value | Design Value | Status |
|---|---|---|---|
| Via drill (2L) | 0.3mm | | [ ] |
| Via drill (4L+) | 0.2mm | | [ ] |
| Via pad (2L) | 0.6mm | | [ ] |
| Via pad (4L+) | 0.45mm | | [ ] |
| PTH drill min | 0.15mm | | [ ] |
| PTH drill max | 6.3mm | | [ ] |
| NPTH drill min | 0.5mm | | [ ] |
| Hole-to-hole | 0.25mm | | [ ] |
| Hole-to-trace | 0.25mm | | [ ] |

**Via Tenting:**
- [ ] Decide: tented (covered by solder mask) or open
- [ ] Tented vias reduce risk of shorts from solder

### 4. Solder Mask

- [ ] Solder mask expansion appropriate (typically 0.05mm)
- [ ] No mask slivers (thin strips between pads)
- [ ] Mask bridge between fine-pitch pads (check 0.5mm pitch and below)
- [ ] Mask color selected (green fastest/cheapest)

### 5. Silkscreen

- [ ] Minimum line width: 0.15mm (0.2mm preferred)
- [ ] Minimum text height: 0.8mm (1.0mm preferred)
- [ ] No silkscreen on pads
- [ ] No silkscreen on exposed copper
- [ ] Reference designators readable
- [ ] Polarity markings present for polarized components
- [ ] Pin 1 indicators visible

**Silkscreen Conflicts:**
- Enable "Subtract soldermask from silkscreen" in plot settings
- Or manually adjust silkscreen graphics

### 6. Component Placement (for Assembly)

**Orientation:**
- [ ] All components on designated side(s)
- [ ] Consistent IC orientation (pin 1 direction)
- [ ] Components accessible for rework

**Spacing:**
- [ ] Minimum component-to-component spacing met
- [ ] Minimum component-to-edge spacing met
- [ ] Tall components don't shadow shorter ones

**Fiducials (for fine-pitch assembly):**
- [ ] Fiducials present if using 0.5mm pitch or finer
- [ ] Minimum 3 fiducials (recommended: 4 corners + near fine-pitch)
- [ ] Fiducial size: 1mm pad with 2mm clearance

### 7. Special Features

**Slots:**
- [ ] Minimum slot width: 0.65mm (metallized), 1.0mm (non-metallized)
- [ ] Slot length ≥ 2x width (ideally 2.5x)

**Edge Plating:**
- [ ] If needed, properly specified

**Castellated Holes:**
- [ ] If needed, minimum half-hole size 0.6mm

### 8. Layer Alignment

- [ ] All layers use same origin
- [ ] Drill file origin matches Gerber origin
- [ ] Outline on Edge.Cuts layer only

## DFM Review Process

### Step 1: Run Final DRC

Verify 0 errors:
```
Inspect → Design Rules Checker
```

### Step 2: Check Clearances

Use KiCad's clearance measurement:
```
Inspect → Measure (Ctrl+M)
```

Verify:
- Trace-to-trace clearance
- Trace-to-via clearance
- Trace-to-edge clearance

### Step 3: Review Layer by Layer

View each layer independently:
1. F.Cu - Check routing, pours
2. B.Cu - Check routing, ground pour
3. F.Silkscreen - Check readability
4. B.Silkscreen - Check if needed
5. F.Mask - Check pad exposure
6. Edge.Cuts - Check outline is closed

### Step 4: 3D Model Final Check

- [ ] All components present
- [ ] No component collisions
- [ ] Mounting holes clear
- [ ] Connectors accessible
- [ ] Board fits intended enclosure

### Step 5: Generate Test Gerbers

Generate preliminary Gerbers for review:
```bash
kicad-cli pcb export gerbers --layers F.Cu,B.Cu,F.Mask,B.Mask,F.Silkscreen,Edge.Cuts project.kicad_pcb
```

### Step 6: View in External Gerber Viewer

Use one of:
- gerbv (open source)
- Online viewer at JLCPCB
- KiCad's built-in Gerber viewer

Check:
- [ ] All layers align correctly
- [ ] No missing features
- [ ] Board outline correct
- [ ] Drill file matches via/hole positions

## Common DFM Issues

| Issue | Impact | Fix |
|---|---|-----|
| Trace too close to edge | Board rejected | Move trace inward |
| Acid trap | Etching problem | Round corners |
| Copper sliver | Lifting copper | Merge or remove |
| Missing mask | Unwanted solder | Add mask |
| Silkscreen on pad | Solder issue | Move silkscreen |
| No fiducials | Assembly alignment | Add fiducials |

## Output Summary

```
## DFM Review Complete

### Results
- Trace/space violations: [count]
- Drill violations: [count]
- Mask violations: [count]
- Silkscreen issues: [count]

### Required Fixes
1. [Description] - [Location]
2. [Description] - [Location]

### Ready for Production
[ ] Yes - proceed to /pcb-manufacture
[ ] No - fix issues first

### Files Generated
- tmp/dfm_gerbers/ (for review)
```

## Success Criteria

- [ ] All DFM checks pass
- [ ] Gerbers verified in external viewer
- [ ] No manufacturing warnings expected
- [ ] Ready for PRR gate

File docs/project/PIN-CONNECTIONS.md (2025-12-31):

# Pin Connections: Singing Birthday Card

Complete pin allocation and connection mapping for schematic design.

---

## System Block Diagram

```
                    CR2032 Battery (3V)
                           │
                           ▼
                    ┌──────────────┐
                    │   +3V Rail   │
                    └──────┬───────┘
                           │
         ┌─────────────────┼─────────────────┐
         │                 │                 │
         ▼                 ▼                 ▼
    ┌─────────┐      ┌──────────┐      ┌─────────┐
    │  U1     │ SPI  │    U2    │      │  LS1    │
    │ISD3900  │◄────►│ W25Q16   │      │ Speaker │
    │         │      │  Flash   │      │         │
    └────┬────┘      └──────────┘      └────┬────┘
         │                                   │
         └───────────────────────────────────┘
                    SPK+/SPK-

    ┌─────────┐      ┌──────────┐      ┌─────────┐
    │   R1    │      │   SW1    │      │   J2    │
    │  LDR    │      │  Button  │      │Pull-Tab │
    │ GL5528  │      │          │      │         │
    └─────────┘      └──────────┘      └─────────┘
         │                │                 │
         └────────────────┴─────────────────┘
                    TRIGGER (GPIO)
```

---

## U1: ISD3900FYI (Audio Processor)

48-pin LQFP, LCSC: C2613393

### Power Requirements
| Parameter | Min | Typ | Max | Unit |
|---|-----|-----|-----|---|
| VCC/VCCa | 2.7 | 3.0 | 3.6 | V |
| Standby Current | - | 1 | - | uA |
| Playback Current | - | 15 | 25 | mA |

### Complete Pin Table

| Pin | Name | Type | Net | Connection | Notes |
|-----|---|---|-----|---|---|
| 1 | NC | - | - | Float | No connect |
| 2 | CSB | Output | SPI_CS | U2./CS | External flash chip select |
| 3 | DI | Input | SPI_MISO | U2.DO | Data from external flash |
| 4 | I2S_SDI/GPIO7 | I/O | - | Float/GPIO | Optional |
| 5 | I2S_SCK/GPIO6 | I/O | - | Float/GPIO | Optional |
| 6 | I2S_WS/GPIO5 | I/O | - | Float/GPIO | Optional |
| 7 | I2S_SDO/GPIO4 | I/O | - | Float/GPIO | Optional |
| 8 | NC | - | - | Float | No connect |
| 9 | NC | - | - | Float | No connect |
| 10 | VSS | Power | GND | Ground | **Digital ground** |
| 11 | VCC | Power | +3V | Battery+ | **100nF to GND** |
| 12 | VREG | Power | VREG | Regulator out | **10uF to GND** |
| 13 | MISO | Output | - | Float | Host SPI (not used in standalone) |
| 14 | SCLK | Input | - | Float | Host SPI (not used in standalone) |
| 15 | SSB | Input | - | Tie HIGH | Host SPI chip select (not used) |
| 16 | MOSI | Input | - | Float | Host SPI (not used in standalone) |
| 17 | VCCD_PWM | Power | +3V | Battery+ | **100nF to GND** |
| 18 | SPK+ | Output | SP+ | LS1.1 | Speaker + |
| 19 | VSSD_PWM | Power | GND | Ground | Speaker ground |
| 20 | SPK- | Output | SP- | LS1.2 | Speaker - |
| 21 | VCCD_PWM | Power | +3V | Battery+ | **100nF to GND** |
| 22 | NC | - | - | Float | No connect |
| 23 | NC | - | - | Float | No connect |
| 24 | NC | - | - | Float | No connect |
| 25 | INTB | Output | - | Float | Interrupt (optional) |
| 26 | RDY/BSYB | Output | - | Float | Ready/Busy (optional) |
| 27 | RESET | Input | RESET | 10k to VCC | Active low, needs pull-up |
| 28 | DO | Output | SPI_MOSI | U2.DI | Data to external flash |
| 29 | CLK | Output | SPI_SCK | U2.CLK | External flash clock |
| 30 | GPIO3 | I/O | TRIGGER | R1, SW1, J2 | **Trigger input** |
| 31 | GPIO2 | I/O | - | Float | Optional |
| 32 | GPIO1 | I/O | - | Float | Optional |
| 33 | NC | - | - | Float | No connect |
| 34 | NC | - | - | Float | No connect |
| 35 | XTALOUT | Output | - | Float | Internal oscillator used |
| 36 | XTALIN | Input | - | Float | Internal oscillator used |
| 37 | NC | - | - | Float | No connect |
| 38 | GPIO0 | I/O | - | Float | Optional |
| 39 | NC | - | - | Float | No connect |
| 40 | NC | - | - | Float | No connect |
| 41 | AUDOUT | Output | - | Float | Audio out (not used) |
| 42 | AUXOUT | Output | - | Float | Aux out (not used) |
| 43 | VCCa | Power | +3V | Battery+ | **100nF to GND** |
| 44 | VSSA | Power | GND | Ground | **Analog ground** |
| 45 | ANAOUT/MIC- | I/O | - | Float | Mic- (not used) |
| 46 | ANAIN/MIC+ | I/O | - | Float | Mic+ (not used) |
| 47 | AUXIN | Input | - | Float | Aux in (not used) |
| 48 | NC | - | - | Float | No connect |

### ISD3900 Power Pin Summary
| Pin | Name | Capacitor |
|-----|---|---|
| 11 | VCC | 100nF |
| 12 | VREG | 10uF (regulator output) |
| 17 | VCCD_PWM | 100nF |
| 21 | VCCD_PWM | 100nF |
| 43 | VCCa | 100nF |

**Total decoupling: 4x 100nF + 1x 10uF**

### ISD3900 External Flash Interface (to W25Q16)
| Signal | ISD3900 Pin | Direction | Flash Pin | Notes |
|---|---|---|---|---|
| CSB | 2 | Out | U2.1 (/CS) | Flash chip select |
| DI | 3 | In | U2.2 (DO) | Data from flash |
| DO | 28 | Out | U2.5 (DI) | Data to flash |
| CLK | 29 | Out | U2.6 (CLK) | Flash clock |

**Note:** Pins 13-16 (MISO, SCLK, SSB, MOSI) are the HOST SPI interface for external MCU control. In standalone mode with internal oscillator, these are not used.

---

## U2: W25Q16JVSSIQ (SPI Flash)

8-pin SOIC, LCSC: C131024

### Specifications
| Parameter | Value |
|---|---|
| Capacity | 16 Mbit (2 MB) |
| Voltage | 2.7V - 3.6V |
| SPI Clock | Up to 133 MHz |
| Current (read) | 4 mA typ |
| Current (standby) | 1 uA typ |

### Pin Table (SOIC-8)

| Pin | Name | Type | Net | Connection | Notes |
|-----|---|---|-----|---|---|
| 1 | /CS | Input | SPI_CS | U1.15 | Active low chip select |
| 2 | DO (IO1) | Output | SPI_MISO | U1.13 | Data out |
| 3 | /WP (IO2) | Input | +3V | Pull HIGH | Disable write protect |
| 4 | GND | Power | GND | Ground | |
| 5 | DI (IO0) | Input | SPI_MOSI | U1.16 | Data in |
| 6 | CLK | Input | SPI_SCK | U1.14 | SPI clock |
| 7 | /HOLD (IO3) | Input | +3V | Pull HIGH | Disable hold |
| 8 | VCC | Power | +3V | Battery+ | **100nF to GND** |

### W25Q16 Notes
- Pins 3 and 7 must be tied HIGH to disable write protect and hold functions
- 100nF decoupling required on VCC

---

## LS1: KLJ-01304T-08R07W (Speaker)

4-pin SMD speaker, 8 ohm, 0.7W

### Pin Table

| Pin | Name | Net | Connection |
|-----|---|-----|---|
| 1 | + | SP+ | U1.18 (SPK+) |
| 2 | - | SP- | U1.20 (SPK-) |
| 3 | (mounting) | - | Mechanical |
| 4 | (mounting) | - | Mechanical |

**Note:** Differential output from ISD3900 Class D amplifier (SPK+/SPK-)

---

## R1: GL5528 (Light Dependent Resistor)

Through-hole photoresistor, LCSC: C10081

### Specifications
| Parameter | Value |
|---|---|
| Light resistance (10 lux) | 10-20 kOhm |
| Dark resistance | > 1 MOhm |
| Max voltage | 150V DC |
| Spectral peak | 540nm (green) |
| Response time | ~30ms |

### Connection

```
+3V ──┬── R1 (GL5528) ──┬── GND
      │                 │
      └── R2 (10k) ─────┴── TRIGGER (GPIO30)
```

Voltage divider:
- Dark: TRIGGER ~ 0V (LDR high resistance)
- Light: TRIGGER ~ VCC * (10k / (10k + LDR))
- At 10 lux (10-20k LDR): ~1.0-1.5V

---

## SW1: TL3342 (Tactile Switch)

4-pin SPST momentary switch

### Connection

```
TRIGGER ────── SW1 ────── GND
```

Active low - pressing connects TRIGGER to GND.

---

## J2: Pull-Tab Connector

2-pin header for pull-tab trigger

### Connection

```
TRIGGER ────── J2.1
GND     ────── J2.2
```

Pull-tab removes to break connection, triggering playback.

---

## Passive Components

| Ref | Value | Package | Net 1 | Net 2 | Purpose |
|-----|---|---|---|---|---|
| C1 | 100nF | 0603 | +3V | GND | U1.VCC decoupling |
| C2 | 10uF | 0805 | VREG | GND | U1.VREG bulk |
| C3 | 1uF | 0603 | +3V | GND | General filtering |
| C4 | 100nF | 0603 | +3V | GND | U1.VCCD decoupling |
| C5 | 10uF | 0805 | +3V | GND | Bulk capacitor |
| C6 | 100nF | 0603 | +3V | GND | U2.VCC decoupling |
| R1 | GL5528 | THT | +3V | TRIGGER | LDR (light sensor) |
| R2 | 10k | 0603 | TRIGGER | GND | Pull-down for LDR divider |
| R3 | 10k | 0603 | +3V | RESET | Reset pull-up |
| R4 | 10k | 0603 | - | - | Spare |

---

## Net List Summary

| Net Name | Source | Destinations | Purpose |
|---|---|---|---|
| +3V | BT1+ | U1.11,17,21,43, U2.3,7,8, R1, R3, C1-6 | 3V power |
| GND | BT1- | U1.10,19,44, U2.4, R2, SW1, J2.2, C1-6 | Ground |
| VREG | U1.12 | C2 | Internal regulator |
| SPI_MOSI | U1.28 (DO) | U2.5 (DI) | Data to flash |
| SPI_MISO | U2.2 (DO) | U1.3 (DI) | Data from flash |
| SPI_SCK | U1.29 (CLK) | U2.6 (CLK) | Flash clock |
| SPI_CS | U1.2 (CSB) | U2.1 (/CS) | Flash chip select |
| SP+ | U1.18 | LS1.1 | Speaker + |
| SP- | U1.20 | LS1.2 | Speaker - |
| TRIGGER | U1.30 | R1, R2, SW1, J2.1 | Trigger input |
| RESET | U1.27 | R3 | Reset with pull-up |

---

## Power Budget

| Component | Mode | Current (mA) | Duty | Avg (mA) |
|---|---|---|---|---|
| U1 ISD3900 | Playback | 15 | 10% | 1.5 |
| U1 ISD3900 | Standby | 0.001 | 90% | 0.0009 |
| U2 W25Q16 | Read | 4 | 5% | 0.2 |
| U2 W25Q16 | Standby | 0.001 | 95% | 0.001 |
| **Total Average** | | | | **~1.7** |

CR2032 capacity: 220 mAh
**Estimated standby life:** 220 / 0.002 = **>4 years**
**Estimated active life:** 220 / 1.7 = **~130 hours** continuous play

---

## Signal Routing Priority

1. **Power (+3V, GND)** - Wide traces (0.3mm+), short paths, star ground
2. **SPI bus** - Keep together, max 25mm length at 10MHz
3. **Speaker (SP+/SP-)** - Differential pair, away from sensitive signals
4. **Trigger** - Can be long, not speed-critical
5. **Reset** - Short to pull-up resistor

---

## Design Checklist

### Power
- [x] All VCC pins identified (U1: 11,17,21,43; U2: 8)
- [x] All GND pins identified (U1: 10,19,44; U2: 4)
- [x] Decoupling capacitors assigned (4x 100nF + 2x 10uF)
- [x] VREG output capacitor (10uF on pin 12)

### SPI Interface
- [x] MOSI connected (U1.16 → U2.5)
- [x] MISO connected (U2.2 → U1.13)
- [x] SCK connected (U1.14 → U2.6)
- [x] CS connected (U1.15 → U2.1)
- [x] W25Q16 /WP tied HIGH (pin 3)
- [x] W25Q16 /HOLD tied HIGH (pin 7)

### Trigger Input
- [x] GPIO30 selected for trigger
- [x] LDR voltage divider designed
- [x] Button connected
- [x] Pull-tab connector included

### Speaker
- [x] Differential output (SPK+/SPK-)
- [x] 4-pin speaker footprint

### Unused Pins
- [x] NC pins floating (per datasheet)
- [x] Unused GPIO pins floating
- [x] I2C pins (CSB, DI) tied appropriately
- [x] Crystal pins floating (internal oscillator)

---

## Open Questions (Resolved)

1. **Crystal needed?** NO - ISD3900 has internal oscillator
2. **LDR pull-up or pull-down?** PULL-DOWN (R2 to GND)
3. **Reset circuit?** 10k pull-up to VCC
4. **Speaker coupling capacitor?** NO - Class D differential output

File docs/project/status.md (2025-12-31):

# Currently Working On

## Project: Singing Birthday Card Module

### Status: Schematic complete, PCB needs routing

### Design Decisions Made

1. **No USB** - Dropped USB requirement (not available on LCSC, needs 5V)
2. **SPI Programming** - Each card programmed individually via SPI programmer
3. **ISD3900FYI** - Nuvoton audio playback IC with built-in Class D amp
4. **4-pin Speaker** - KLJ-01304T-08R07W SMD speaker with proper symbol

### Completed Tasks

- [x] Component research and selection
- [x] KiCad schematic design (A5 page, compact layout)
- [x] Symbol library with embedded symbols
- [x] PCB layout (components placed)
- [x] 3D models configured

### Pending Tasks

1. [ ] **Route PCB traces** - Open in KiCad, use File > Export > Specctra DSN, run FreeRouting, import SES
2. [ ] Run DRC check
3. [ ] Generate Gerbers and BOM for JLCPCB
4. [ ] Order prototype batch

### PCB Routing Instructions

1. Open `kicad/singingcard.kicad_pcb` in KiCad
2. File > Export > Specctra DSN
3. Run FreeRouting: `java -jar freerouting.jar`
4. Load DSN, autoroute, export SES
5. In KiCad: File > Import > Specctra Session
6. Run DRC to verify

### Key Files

- `kicad/create_schematic_v5.py` - Schematic generator script
- `kicad/singingcard.kicad_sch` - KiCad schematic
- `kicad/singingcard.kicad_pcb` - KiCad PCB layout
- `kicad/specs.md` - Project specifications
- `kicad/component-selection.md` - Full component research and BOM

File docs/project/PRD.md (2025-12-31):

# Project: Singing Birthday Card Module

## Overview
- **Purpose**: Cheap module to play audio when birthday card opens
- **Application**: Gift/novelty, hidden inside greeting cards
- **Reference**: Commercial singing cards, ISD1820 modules

## Components (To Research)
- **Audio IC**: MP3 decoder with USB upload (MH2024K-24SS or WT2003S)
- **Speaker**: 23-28mm, 8 ohm, 0.5-1W
- **Light sensor**: LDR (GL5528) for open-card detection
- **Button**: Optional tactile switch
- **Pull-tab switch**: Break-contact mechanism

## Power
- **Input**: CR2032 coin cell (3V)
- **Current estimate**: <100mA during playback
- **No charging**: disposable battery

## Triggers (Jumper Selectable)
1. Light sensor - detects card opening
2. Button - manual press
3. Pull-tab - paper tab removal completes circuit

## Physical
- **Size**: ~85x55mm (credit card), flexible
- **Shape**: Rectangular
- **Mounting**: Glued/taped inside card

## Fabrication
- **Layers**: 2
- **Quantity**: 5-10 prototypes
- **Budget**: <$3/unit target
- **Assembly**: JLCPCB SMT
- **Solder mask**: Green
- **Silkscreen**: White
- **Finish**: HASL lead-free

## Open Questions
- [ ] Exact MP3 chip selection (check LCSC stock)
- [ ] Speaker driver - built into chip or need amp?
- [ ] USB connector - Micro or USB-C?

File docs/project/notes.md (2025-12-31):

# Notes

Miscellaneous notes and learnings during the project.

---

## Setup Notes (Dec 30, 2025)

- KiCad 9.0.6 is installed and kicad-cli works
- IPC API should be enabled in KiCad Preferences > Plugins
- All Python packages in venv to keep system clean
- FreeRouting JAR still needs to be downloaded for auto-routing

## Tool Quirks

*To be filled as we discover them*

## JLCPCB Notes

*To be filled when we work with JLCPCB*

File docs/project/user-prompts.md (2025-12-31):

# User Prompts Log

This file tracks all user prompts and major decisions throughout the project.

---

## Session 1: December 30, 2025

### Initial Research Request

> using perplexity find the best way to use kicad as claude code agent such as yourself and use plugings and everything too. i need you to do auto routing, use the jlc plug in library and select chips. also then look at if you can use the jlcpcb api plugin to order it yourself. be thorough about your research. extremely thorough. search far and wide find the best tools. maybe it's an MCP servert or maybe it's just the kicad api directly. An importatn note is that you need to use third party pluging such as autorouter and stuff. you also need ot be ablet oclean up any mistakes, and furethermore also inspect the schematic and layout visually using screenshots of kicad. you dont necessariliy need kicad to visuallze you could use some third party app. I just have no idea what's out there. find the best workflow for an agent using kicad.

**Result:** Created comprehensive research document `kicad-agent-workflow-research.md`

---

### Workflow Setup Request

> install all the tools that you think are best. keep them in another document describing everthing. remember to keep it concise. to put it into perspective i want to ask you to design and order an entire PCB from start to end i dont want to actually do anything myself except give you the project requirements and maybe set up api keys and whatnot. settle on the best tools write that in a plan. you will need to select components, make sure they're available on jlc, with the jlc tools plug in or the api, recurse on that in case it's not available, you'll need to research all the chips and their pins and connections, then you'll need to connect everything together in the schematic with labels and stuff. you'll need ot make sure it visually looks correct and things dont overlap and stuff, then you'll have to do the routing, i'll specifyt the rough board size and shape, you'll arrange things using a tools or something then you'll need to run the design rules checker and verify everything. btw you'll need to make sure the curtrent requremetns of ttraces are good. then you'll export it and use teh jlc api if you can to order it. you also need to make sure by the way taht everything is assembleable by jlc. you'll ask the user for relevant questions regarding teh fabrication if not specified such as color and time for fabrications and whatnot. make sure you keep notes of things in relevant markdown files. keep it well organized, keep in mind that you only have so long of a context length. you'll need a couple files such as a claude skill for kicad usage, just make that a local project skill, you'll need a md file for now to just make sure you install and document all the thigns you installed. you'll need a file for the actual specificatiosn of the project where you note what the user wants. and you may need other md files for anything else like maybe misc notes or idk what.
> so by the way I will maybe check things here and there but i hope to not have to. i'll give you project requirements later, just get your notes and skill set up. settle on what tools you want to use and how you're going to format your notes. this is goingto be a really long project to we need to stay on top of it

**Decision:** Use kicad-mcp-python, FreeRouting, SKiDL, easyeda2kicad, KiBot

---

### Directory Corrections

> all kicad files shall go in a folder within the current folder called kicad. you also need to set up the repo now. add a readme saying this is an attempt to get claude code to make a pcb front start to finish

**Action:** Updated directory structure, initialized git repo, created README

---

### Virtual Environment & Prompts Tracking

> the kicad root folder shoudl jsut be right in a fodler in teh current folder called kicad. make sure anything you install is in a venv. keep track btw of all prompts i give you in a file called user promts.md

**Action:** All Python packages to be installed in venv/, created this file

---

## Project Requirements

*To be added when user provides project specifications*

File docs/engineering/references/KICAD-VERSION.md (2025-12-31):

# KiCad Version Notes

This project uses **KiCad 9.0.x** (December 2025).

---

## Library Formats (KiCad 8/9)

| Type | Extension | Container | Notes |
|---|---|---|---|
| **Symbols** | `.kicad_sym` | Single file | One file can contain multiple symbols |
| **Footprints** | `.kicad_mod` | `.pretty/` folder | One file per footprint in a `.pretty` directory |
| **3D Models** | `.wrl`, `.step` | Any folder | Typically in `.3dshapes/` directory |
| **Schematic** | `.kicad_sch` | - | S-expression format, version 20250114 for KiCad 9 |
| **PCB** | `.kicad_pcb` | - | S-expression format |
| **Project** | `.kicad_pro` | - | JSON format in KiCad 6+, S-expression before |

---

## Library Table System

KiCad uses library tables to locate libraries:

| File | Scope | Purpose |
|---|---|---|
| `fp-lib-table` | Project/Global | Maps footprint library nicknames to paths |
| `sym-lib-table` | Project/Global | Maps symbol library nicknames to paths |

### Path Variables

| Variable | Meaning |
|---|---|
| `${KIPRJMOD}` | Project directory (relative paths) |
| `${KICAD9_SYMBOL_DIR}` | Global KiCad symbol libraries |
| `${KICAD9_FOOTPRINT_DIR}` | Global KiCad footprint libraries |
| `${KICAD9_3DMODEL_DIR}` | Global KiCad 3D models |

**Always use `${KIPRJMOD}` for project-local libraries** to ensure portability.

---

## Key Changes from KiCad 7

1. **Fields in Footprints** (KiCad 8+)
   - Footprints now have named fields like symbols
   - Default fields: Reference, Value, Footprint, Datasheet, Description
   - Fields sync between schematic and PCB

2. **File Format Versions**
   - KiCad 9 schematic version: 20250114
   - KiCad 9 PCB version: 20250114
   - Older KiCad versions cannot open files saved in newer versions

3. **Embedded Symbols in Schematic**
   - KiCad 8+ schematics contain `lib_symbols` section
   - All used symbols are embedded in the schematic file
   - Schematic is self-contained (doesn't require external symbol libraries)

4. **Library Upgrade Command**
   ```bash
   kicad-cli fp upgrade --force libs/project.pretty
   kicad-cli sym upgrade libs/project.kicad_sym
   ```

---

## Project Library Structure

```
project/
├── kicad/
│   ├── libs/
│   │   ├── project.kicad_sym          # Symbol library
│   │   └── project.pretty/            # Footprint library folder
│   │       ├── Component1.kicad_mod
│   │       └── Component2.kicad_mod
│   ├── 3dmodels/ or libs/project.3dshapes/
│   │   ├── Component1.wrl
│   │   └── Component1.step
│   ├── fp-lib-table                   # Footprint library config
│   ├── sym-lib-table                  # Symbol library config
│   ├── project.kicad_pro              # Project file
│   ├── project.kicad_sch              # Schematic
│   └── project.kicad_pcb              # PCB
```

---

## Importing from LCSC/EasyEDA

The `easyeda2kicad` tool imports components from LCSC:

```bash
easyeda2kicad --lcsc_id CXXXXXX --full --output libs/project.kicad_sym
```

**Important:** EasyEDA exports older format files. Upgrade after import:

```bash
kicad-cli fp upgrade --force libs/project.pretty
```

---

## CLI Commands (KiCad 9)

### Rendering
```bash
kicad-cli pcb render --output image.png --side top project.kicad_pcb
kicad-cli pcb render --perspective --rotate "45,0,45" project.kicad_pcb
```

### Design Checks
```bash
kicad-cli sch erc --output erc.json --format json project.kicad_sch
kicad-cli pcb drc --output drc.json --format json project.kicad_pcb
```

### Export
```bash
kicad-cli pcb export gerbers --output gerbers/ project.kicad_pcb
kicad-cli pcb export drill --output gerbers/ project.kicad_pcb
kicad-cli pcb export pos --output positions.csv project.kicad_pcb
kicad-cli pcb export step --output model.step project.kicad_pcb
```

---

## Compatibility Notes

- **Read-only formats**: Eagle, Altium, CADSTAR (can open, cannot save)
- **Legacy KiCad**: `.mod` files (KiCad 4 and earlier) are read-only
- **Forward compatibility**: None - newer files won't open in older KiCad
- **Backward compatibility**: KiCad 9 can open KiCad 4+ files

---

## References

- [KiCad Documentation](https://docs.kicad.org/9.0/en/)
- [KiCad Library Conventions](https://klc.kicad.org)
- [KiCad CLI Reference](https://docs.kicad.org/9.0/en/cli/cli.html)

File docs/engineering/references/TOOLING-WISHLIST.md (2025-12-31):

# Tooling Wishlist for PCB Development

Tools that would significantly improve Claude Code's ability to work with KiCad and PCB projects.

---

## Already Exists in KiCad 9 CLI

Reference these capabilities - they're already available!

### PCB Operations (`kicad-cli pcb`)

```bash
# 3D Rendering
kicad-cli pcb render --side front --output front.png project.kicad_pcb
kicad-cli pcb render --side back --width 1600 --height 1200 project.kicad_pcb

# Design Rules Check
kicad-cli pcb drc --output drc-report.json project.kicad_pcb

# Gerber Export
kicad-cli pcb export gerbers --output gerbers/ project.kicad_pcb

# Drill Files
kicad-cli pcb export drill --output gerbers/ --format excellon project.kicad_pcb

# Pick-and-Place / Position File
kicad-cli pcb export pos --output positions.csv --format csv project.kicad_pcb

# 3D Model Export
kicad-cli pcb export step --output board.step project.kicad_pcb
kicad-cli pcb export vrml --output board.wrl project.kicad_pcb
kicad-cli pcb export glb --output board.glb project.kicad_pcb

# 2D Exports
kicad-cli pcb export svg --layers F.Cu,B.Cu --output layers.svg project.kicad_pcb
kicad-cli pcb export pdf --layers F.Cu,B.Cu --output layers.pdf project.kicad_pcb
kicad-cli pcb export dxf --output board.dxf project.kicad_pcb

# Manufacturing Formats
kicad-cli pcb export ipc2581 --output board.xml project.kicad_pcb
kicad-cli pcb export odb --output odb_output/ project.kicad_pcb
```

### Schematic Operations (`kicad-cli sch`)

```bash
# Electrical Rules Check
kicad-cli sch erc --output erc-report.json project.kicad_sch

# Bill of Materials
kicad-cli sch export bom --output bom.csv project.kicad_sch

# Netlist Export
kicad-cli sch export netlist --output netlist.net project.kicad_sch

# PDF/SVG Export
kicad-cli sch export pdf --output schematic.pdf project.kicad_sch
kicad-cli sch export svg --output schematic.svg project.kicad_sch
```

### What's NOT in kicad-cli (gaps to fill)

| Capability | Status | Workaround |
|---|---|---|
| Schematic 3D/image render | Missing | Export SVG/PDF |
| DSN export (autorouting) | Missing | Use KiCad Python |
| SES import (autorouting) | Missing | Use KiCad Python |
| Component placement | Missing | Edit .kicad_pcb directly |
| Net/component queries | Missing | Parse files or use Python |
| Symbol/footprint creation | Limited | Use fp/sym subcommands |

---

## High Priority

### 1. KiCad Python Bridge (MCP Server)

**Problem:** KiCad's Python API (`pcbnew`) only works inside KiCad's bundled Python, requiring complex subprocess calls.

**Desired Tool:** An MCP server that exposes KiCad's Python API.

```json
{
  "tool": "kicad_pcb",
  "action": "get_components",
  "file": "project.kicad_pcb"
}
```

**Capabilities:**
- Read/write PCB properties
- List components with positions
- Get net connections
- Run DRC programmatically
- Export DSN/import SES (for autorouting)
- Modify footprints
- Update 3D model paths

**Implementation:**
```python
# MCP Server using KiCad's Python
from mcp import Server
import pcbnew

@server.tool("kicad.get_components")
def get_components(pcb_path: str):
    board = pcbnew.LoadBoard(pcb_path)
    components = []
    for fp in board.GetFootprints():
        components.append({
            "ref": fp.GetReference(),
            "value": fp.GetValue(),
            "x": fp.GetPosition().x / 1e6,
            "y": fp.GetPosition().y / 1e6,
            "rotation": fp.GetOrientation().AsDegrees()
        })
    return components
```

---

### 2. JLCPCB Parts API Client

**Problem:** Have to manually search JLCPCB website for parts, check stock, verify compatibility.

**Desired Tool:** API client for JLCPCB/LCSC parts database.

```bash
jlcpcb-parts search "100nF 0603" --category basic --in-stock
jlcpcb-parts info C14663  # Get full part details
jlcpcb-parts check-bom bom.csv  # Validate all parts
```

**Features:**
- Search by parameters (value, package, category)
- Filter by Basic/Extended parts
- Real-time stock levels
- Price at quantity breaks
- Footprint/symbol availability
- Datasheet links
- Alternative part suggestions

**Implementation Notes:**
- LCSC has an unofficial API
- Could scrape JLCPCB parts library
- Cache results locally

---

### 3. Schematic Generator Library

**Problem:** Creating schematics programmatically requires understanding KiCad's complex S-expression format.

**Desired Tool:** High-level Python library for schematic generation.

```python
from kicad_schematic import Schematic, Component, Wire, Label

sch = Schematic("project.kicad_sch")

# Add component with automatic symbol lookup
mcu = sch.add_component("ATtiny85", ref="U1", pos=(100, 100))

# Connect pins with automatic wire routing
sch.connect(mcu.pin("VCC"), sch.power("+3V3"))
sch.connect(mcu.pin("GND"), sch.power("GND"))

# Add decoupling cap near power pins
cap = sch.add_component("100nF", ref="C1", near=mcu.pin("VCC"))
sch.connect(cap.pin(1), mcu.pin("VCC"))
sch.connect(cap.pin(2), sch.power("GND"))

sch.save()
```

**Features:**
- Component placement with collision avoidance
- Automatic wire routing
- Symbol library integration
- Hierarchical sheet support
- Net label management
- ERC pre-validation

---

### 4. Gerber Analyzer/Validator

**Problem:** Cannot verify Gerber files without external viewer.

**Desired Tool:** CLI tool to analyze and validate Gerbers.

```bash
gerber-check output/gerbers/ --rules jlcpcb
```

**Output:**
```
Gerber Analysis Report
======================
Board size: 50.0 x 40.0 mm
Layers: 6 (F.Cu, B.Cu, F.Mask, B.Mask, F.Silk, Edge.Cuts)
Drill holes: 45 (min: 0.3mm, max: 3.2mm)

JLCPCB Compatibility:
[PASS] Board size within limits
[PASS] Minimum trace width: 0.15mm (min: 0.127mm)
[PASS] Minimum spacing: 0.15mm (min: 0.127mm)
[PASS] Minimum drill: 0.3mm (min: 0.3mm)
[WARN] Via count: 45 (consider reducing for cost)
[PASS] All layers present

Estimated cost: $2.00 (5 pcs) + $3.00 assembly setup
```

**Features:**
- Parse all Gerber/Excellon formats
- Check against manufacturer DFM rules
- Generate visual diff between versions
- Estimate manufacturing cost
- Detect common issues (acid traps, slivers)

---

## Medium Priority

### 5. Component Footprint Validator

**Problem:** Footprints from various sources may not match actual component dimensions.

**Desired Tool:** Validate footprints against datasheets.

```bash
footprint-check SOIC-8.kicad_mod --datasheet W25Q16JV.pdf
```

**Features:**
- Parse datasheet PDF for package dimensions
- Compare against footprint pads
- Check recommended land pattern
- Verify 3D model alignment
- Generate correction suggestions

---
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

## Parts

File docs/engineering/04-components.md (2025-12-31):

# PCB Component Selection

Phase 3 of PCB Systems Engineering Lifecycle.

## Activation
- User says: /pcb-components, select components, find parts, jlcpcb parts
- After SRR gate passes

## Purpose

Research, select, and validate components for JLCPCB manufacturing.

## Prerequisites

- SRR complete (PRD, ConOps, ICD approved)
- Functional requirements defined

## Process

### Step 1: Create Function-to-Component Matrix

For each function in the system, identify required component types:

```markdown
| Function | Component Type | Key Parameters |
|----------|---------------|----------------|
| Audio playback | MCU/DSP | Memory, I/O, audio DAC |
| Audio output | Speaker | Size, power, SPL |
| Power regulation | LDO/DC-DC | Vin, Vout, current |
| Storage | Flash | Capacity, interface |
```

### Step 2: JLCPCB Parts Library Search

For each component type, search JLCPCB:

**Search Strategy:**
1. Start with Basic Parts (lowest cost, always in stock)
2. If no Basic option, check Extended Parts
3. Verify stock level > order quantity + 50% margin
4. Check for multiple sources (preferred vs alternate)

**Use Perplexity/Web Search for:**
```
site:jlcpcb.com [component type] [key parameter] basic part
```

**JLCPCB Parts Library URL:**
```
https://jlcpcb.com/parts/componentSearch?searchTxt=[query]
```

### Step 3: Datasheet Analysis

For each selected component:

1. **Download datasheet** to `docs/datasheets/[part_number].pdf`
2. **Extract key information:**
   - Absolute maximum ratings
   - Recommended operating conditions
   - Pin configuration
   - Typical application circuit
   - Footprint/package dimensions

3. **Create component notes** in `docs/research/[part_number].md`:
```markdown
# [Part Number] - [Description]

## Source
- LCSC: [LCSC number]
- Category: Basic/Extended
- Stock: [quantity]
- Unit Price: [price]

## Key Specifications
- Parameter 1: value
- Parameter 2: value

## Application Notes
- Required external components
- Layout considerations
- Thermal requirements

## Risks
- [Any concerns]
```

### Step 4: Schematic Symbol & Footprint Check

For each component, verify:
- [ ] Symbol exists in JLCPCB library or create custom
- [ ] Footprint matches datasheet exactly
- [ ] 3D model available (nice to have)

If creating custom:
- Save to `kicad/libs/[project].kicad_sym`
- Save to `kicad/libs/[project].pretty/`

### Step 5: Create BOM Draft

Create `kicad/output/bom/BOM_draft.csv`:

```csv
Designator,Value,Footprint,LCSC,Quantity,Category,Unit Price,Total
U1,ISD3900FYI,LQFP-48,C123456,1,Extended,$2.50,$2.50
C1,100nF,0603,C14663,1,Basic,$0.01,$0.01
```

### Step 6: Component Selection Matrix

Create `docs/research/component-selection.md`:

```markdown
# Component Selection Matrix

## Microcontroller / Audio IC

| Option | Part Number | LCSC | Category | Price | Pros | Cons |
|--------|-------------|------|----------|-------|------|------|
| Selected | ISD3900FYI | C... | Extended | $2.50 | Built-in DAC | Complex |
| Alt 1 | ATtiny85 | C... | Basic | $0.80 | Simple | No DAC |
| Alt 2 | ESP32 | C... | Extended | $3.00 | WiFi | Overkill |

**Decision:** ISD3900FYI selected because [rationale]

## Power Regulator
[Same format]

## Speaker
[Same format]
```

### Step 7: JLCPCB Compatibility Verification

Run through checklist for each component:

```markdown
### JLCPCB Assembly Compatibility

| Component | In Library | Stock OK | Package OK | Notes |
|-----------|------------|----------|------------|-------|
| U1 | Yes | 500+ | LQFP-48 | |
| U2 | Yes | 1000+ | SOIC-8 | |
| R1 | N/A | N/A | THT | Hand solder |
```

**Package Compatibility:**
- SMD: 0201 minimum (0402+ preferred)
- QFP: 0.5mm pitch minimum
- BGA: 0.4mm pitch minimum (may need fiducials)
- THT: Not assembled by JLCPCB (hand solder required)

### Step 8: Risk Assessment

Document component risks:

```markdown
### Component Risks

| Risk | Probability | Impact | Mitigation |
|------|-------------|--------|------------|
| ISD3900 stock out | Low | High | Order early, check alt |
| Speaker size conflict | Medium | Medium | Verify with 3D model |
```

### Step 9: Output Summary

```
## Component Selection Complete

### BOM Summary
- Total components: [count]
- JLCPCB Basic parts: [count]
- JLCPCB Extended parts: [count]
- Manual assembly required: [count]
- Estimated component cost: $[total]

### Key Decisions
1. [Main IC]: [selection] - [rationale]
2. [Power]: [selection] - [rationale]

### Action Items
- [ ] Download remaining datasheets
- [ ] Create custom symbols for: [list]
- [ ] Verify footprints for: [list]

### Next Steps
Run /pcb-pdr to conduct Preliminary Design Review
```

## JLCPCB Search Tips

**Finding Basic Parts:**
- Filter by "Basic Parts" in JLCPCB parts search
- Basic parts have no $3 extended fee
- Common passives (R, C) usually Basic
- Common packages (0402, 0603, 0805) usually Basic

**Stock Levels:**
- Green: Good stock (>1000)
- Yellow: Low stock (100-1000)
- Red: Very low (<100)
- Order early if using low-stock parts

**Price Breaks:**
- Check prices at different quantities
- Extended parts: $3 setup fee (once per order, not per part)

## Success Criteria

- [ ] All functions have selected components
- [ ] All components verified in JLCPCB library
- [ ] Datasheets downloaded for critical parts
- [ ] BOM draft created
- [ ] Component selection matrix documented
- [ ] Risks identified

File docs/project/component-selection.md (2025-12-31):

# Component Selection: Singing Birthday Card Module

## Approach Selected

**SPI Programming Station** - Each card's flash chip is programmed with custom audio before use.

- Audio chip: ISD3900FYI (playback only, built-in speaker amp)
- Storage: Winbond W25Q SPI flash
- Trigger: GL5528 LDR + optional button + pull-tab
- Power: CR2032 (3V)

## Research Findings

### Audio Chips - LCSC Availability

#### NOT Available on LCSC:
| Chip | Notes |
|---|---|
| MH2024K-24SS | MP3 + USB mass storage - **NOT ON LCSC** |
| WT2003S | MP3 + USB mass storage - **NOT ON LCSC** |
| JQ6500 | Popular MP3 module - **NOT ON LCSC** |
| ISD1820 | Classic voice record chip - **NOT ON LCSC** |
| WT588D | Voice chip - **DISCONTINUED** |

#### Available on LCSC (Voice Record/Playback):
| Part Number | LCSC# | Price | Stock | Features | Voltage |
|---|---|---|---|---|---|
| ISD3900FYI | C2613393 | $1.29 | 60 | I2S/SPI, 4-48kHz, playback only, ext flash | 2.7-3.6V |
| ISD3800FYI | C2613397 | $2.07 | 2 | I2S/SPI, 4-48kHz, playback only | 2.7-5.5V |
| ISD1730SY | C2613883 | $4.84 | 10 | SPI, 4-12kHz, record/playback | 2.4-5.5V |

**Note**: ISD chips are designed for voice prompts (low bitrate), not MP3 music playback. They require external flash for longer recordings and don't have USB mass storage.

### Light Sensor (LDR) - Available on LCSC
| Part Number | LCSC# | Price (10+) | Stock | Specs |
|---|---|---|---|---|
| GL5528 | C125627 | $0.049 | 23,570 | 540nm, 10-20kΩ, Through-hole 3mm |
| GL5528 | C10081 | $0.039 | 10,250 | 540nm, 8-20kΩ, Through-hole 3.4mm |

**Selected**: C10081 (JCHL) - $0.039, good stock

### CR2032 Battery Holder - Available on JLCPCB Parts
| Part Number | JLCPCB# | Price (1+) | Stock | Type |
|---|---|---|---|---|
| CR2032-BS-6-1 | C70377 | $0.17 | 48,239 | SMD |

**Selected**: C70377 - Good stock, SMD mount

### Speakers - To Be Selected
Need: 23-28mm, 8Ω, 0.5-1W
LCSC has 1,400+ speaker options but requires manual filtering.

---

## Three Possible Approaches

### Option A: Simple Voice Chip (Cheapest, No USB)
Use ISD-series or similar voice playback chip.

**Pros:**
- Works with 3V CR2032
- Available on LCSC
- ~$1-2 per chip

**Cons:**
- No USB drag-and-drop upload
- Audio must be pre-programmed via SPI programmer
- Lower audio quality (voice-optimized, not music)

**Good for:** Pre-recorded message cards where audio doesn't change

### Option B: MP3 Module from AliExpress (USB, but Not LCSC)
Source MH2024K or WT2003S module from AliExpress/Alibaba.

**Pros:**
- USB drag-and-drop MP3 upload
- Good audio quality
- Trigger pins available

**Cons:**
- Not available on LCSC (can't do JLCPCB SMT assembly)
- Requires 4.5-5V (NOT compatible with single CR2032)
- Need boost converter or 2x CR2032 in series
- Module cost: ~$1-2 from China

**Good for:** DIY projects where you source modules separately

### Option C: Hybrid PCB + Module
Design PCB with LDR, triggers, battery holder, and space to solder an MP3 module.

**Pros:**
- Can use JLCPCB for PCB fab
- Flexibility to source audio module separately
- Works with existing $1-2 MP3 modules from China

**Cons:**
- Two-stage assembly (PCB + module)
- Still needs 2x CR2032 or LiPo for 5V module
- Total cost likely >$3/unit

---

## Recommendation

Given the requirements, I recommend **reconsidering one of these constraints**:

1. **Drop USB requirement** → Use ISD chip with pre-programmed audio
2. **Change battery to 2x CR2032 or small LiPo** → Can use USB-capable MP3 chip
3. **Accept non-LCSC sourcing** → Buy MH2024K modules from AliExpress

## Next Steps

User decision needed:
- [ ] Which approach to pursue?
- [ ] Is pre-programmed audio acceptable? (no USB)
- [ ] Can we use 2x batteries or different power source?
- [ ] Is non-LCSC module sourcing acceptable?

---

## Final Parts List (BOM)

| Component | Part Number | LCSC/JLCPCB | Qty | Unit Price | Notes |
|---|---|---|-----|---|---|
| Audio IC | ISD3900FYI | C2613393 | 1 | $1.29 | 48-LQFP, 2.7-3.6V, built-in Class D amp |
| SPI Flash | W25Q16JVSSIQ | TBD | 1 | $0.57 | 16Mbit, 2.7-3.6V, SOIC-8 |
| LDR | GL5528 | C10081 | 1 | $0.04 | Light sensor, through-hole |
| Battery Holder | CR2032-BS-6-1 | C70377 | 1 | $0.17 | SMD |
| Speaker | 23mm 8Ω 0.5W | LCSC (TBD) | 1 | $0.45-0.82 | Electromagnetic |
| Crystal | 11.2896MHz | TBD | 1 | ~$0.15 | For audio timing |
| Tactile Switch | 6x6mm | TBD | 1 | ~$0.02 | Optional button trigger |
| Capacitors | 0.1uF, 10uF, etc | TBD | ~5 | ~$0.05 | Decoupling, audio |
| Resistors | Various | TBD | ~4 | ~$0.02 | LDR divider, etc |
| **Subtotal** | | | | **~$2.85** | Components only |

### PCB Cost Estimate
- PCB fab: ~$0.50-1.00/unit at qty 10 (JLCPCB)
- SMT assembly: ~$0.50/unit (extended parts fee)

**Estimated Total: ~$3.50-4.00/unit** (slightly over $3 target)

---

## ISD3900FYI Key Features

From datasheet:
- **Voltage**: 2.7-3.6V (works with 3V CR2032)
- **Speaker output**: Built-in Class D, 350mW @ 3.3V into 8Ω
- **Audio format**: ADPCM (4-bit) or PCM (12-bit)
- **Sample rates**: 8-48kHz
- **Storage**: Up to 128Mbit external SPI flash (64 min @ 8kHz ADPCM)
- **Standby**: ~1µA
- **Package**: LQFP-48 (7x7mm)

### Flash Storage Calculation
W25Q16 = 16Mbit = 2MB storage

| Sample Rate | Compression | Duration |
|---|---|---|
| 8kHz | 4-bit ADPCM | ~8 min |
| 16kHz | 4-bit ADPCM | ~4 min |
| 32kHz | 8-bit PCM | ~1 min |
| 48kHz | 8-bit PCM | ~40 sec |

For 10-20 second audio at decent quality (16-32kHz), W25Q16 is plenty.

---

## SPI Programming Setup

To program custom audio for each card:

1. **Hardware needed**:
   - CH341A USB programmer (~$5) OR
   - Raspberry Pi with SPI interface

2. **Software**:
   - Nuvoton ISD-DMK tools for audio conversion
   - flashrom or similar for SPI flash programming

3. **Process**:
   - Convert MP3/WAV to ISD ADPCM format
   - Program flash chip via SPI
   - Assemble card with programmed flash

---

## Next Steps

- [ ] Confirm exact LCSC part numbers for all components
- [ ] Create KiCad schematic
- [ ] Design PCB layout (~85x55mm)
- [ ] Generate Gerbers and BOM
- [ ] Order prototype batch from JLCPCB

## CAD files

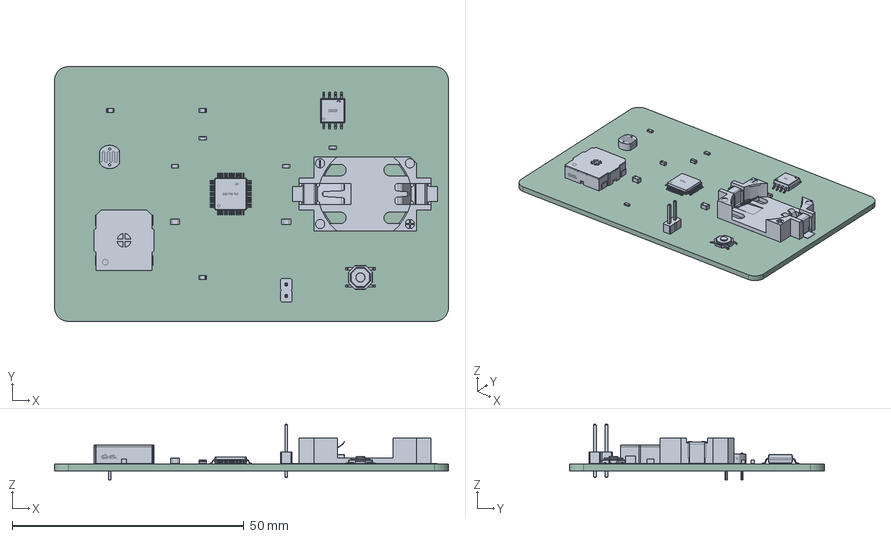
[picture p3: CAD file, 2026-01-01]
images/board.step
85.0 x 55.0 x 12.0 mm
R_0603_1608Metric x 3
C_0603_1608Metric x 4
SOIC-8_L5.3-W5.3-H1.9-LS7.9-P1.27
LQFP-48_L7.0-W7.0-H1.4-LS9.0-P0.50
BAT-SMD_L28.5-W16.0-H5.5-LS31.3_CR2032-BS-6-1
SW_SPST_TL3342
PinHeader_1x02_P2.54mm_Vertical
C_0805_2012Metric x 2
BUZ-SMD_4P-L13.0-W13.0-P11.4-BL
RES-TH_L5.1-W4.3-P3.40-D0.5
singingcard_PCB

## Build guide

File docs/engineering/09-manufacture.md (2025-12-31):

# PCB Manufacturing

Phase 10 of PCB Systems Engineering Lifecycle.

## Activation
- User says: /pcb-manufacture, generate gerbers, order pcb, jlcpcb order
- After PRR gate passes

## Purpose

Generate production files and guide JLCPCB order process.

## Prerequisites

- CDR complete (design frozen)
- DFM review passed
- PRR approval obtained

## Process

### Step 1: Generate Gerbers

**Using Fabrication Toolkit (GUI - Recommended):**
1. Open PCB in KiCad
2. Click Fabrication Toolkit button
3. Configure:
   - [x] Auto-fill zones
   - [ ] User.1 as V-Cut (if using V-cuts)
4. Click Generate
5. Files created in `production/` folder

**Using kicad-cli (Command Line):**
```bash
# Generate Gerbers
kicad-cli pcb export gerbers \
    --output output/gerbers/ \
    --layers F.Cu,B.Cu,F.Silkscreen,B.Silkscreen,F.Mask,B.Mask,Edge.Cuts,F.Paste,B.Paste \
    --subtract-soldermask \
    --use-drill-file-origin \
    project.kicad_pcb

# Generate Drill files
kicad-cli pcb export drill \
    --output output/gerbers/ \
    --format excellon \
    --excellon-units mm \
    --excellon-zeros-format decimal \
    --drill-origin absolute \
    --generate-map \
    --map-format gerberx2 \
    project.kicad_pcb

# Create ZIP
cd output/gerbers && zip -r ../gerbers.zip *
```

### Step 2: Generate BOM

**JLCPCB BOM Format:**
```csv
Comment,Designator,Footprint,LCSC Part #
100nF,"C1,C2,C3",C_0603_1608Metric,C14663
10k,"R1,R2",R_0603_1608Metric,C25804
ISD3900FYI,U1,LQFP-48,C123456
```

**Using Fabrication Toolkit:** Auto-generated in `production/bom.csv`

**Manual export from KiCad:**
```bash
kicad-cli sch export bom --fields "Reference,Value,Footprint,LCSC" project.kicad_sch
```

Then format for JLCPCB requirements.

### Step 3: Generate Pick-and-Place (CPL)

**JLCPCB CPL Format:**
```csv
Designator,Mid X,Mid Y,Rotation,Layer
C1,125.00,121.50,0,top
U1,138.00,127.50,90,top
```

**Using Fabrication Toolkit:** Auto-generated in `production/positions.csv`

**Using kicad-cli:**
```bash
kicad-cli pcb export pos \
    --output output/positions.csv \
    --format csv \
    --units mm \
    --side front \
    --use-drill-file-origin \
    project.kicad_pcb
```

**Note:** May need column name adjustment for JLCPCB.

### Step 4: Verify Files

**Gerber Verification:**
1. Open in external viewer (gerbv, online viewer)
2. Check layer alignment
3. Verify drill positions
4. Check outline matches design

**BOM Verification:**
- [ ] All components listed
- [ ] LCSC part numbers correct
- [ ] Quantities match design
- [ ] No duplicate entries

**CPL Verification:**
- [ ] All components have positions
- [ ] Coordinates reasonable
- [ ] Rotations correct (may need adjustment)

### Step 5: Upload to JLCPCB

**Order Process:**

1. **Go to:** https://jlcpcb.com/

2. **Upload Gerbers:**
   - Click "Add Gerber File"
   - Upload `gerbers.zip`
   - Wait for processing

3. **Configure PCB Options:**
   | Option | Typical Value |
   |--------|---------------|
   | Layers | 2 |
   | Dimensions | Auto-detected |
   | PCB Qty | 5 (minimum) |
   | PCB Thickness | 1.6mm |
   | PCB Color | Green (fastest) |
   | Surface Finish | HASL (cheapest) or ENIG |
   | Copper Weight | 1oz |
   | Remove Order Number | Yes ($1.50 extra) |

4. **Enable Assembly (PCBA):**
   - Toggle "SMT Assembly"
   - Select side (Top/Bottom)
   - PCBA Qty (2-5 typical for prototype)

5. **Upload BOM and CPL:**
   - Add BOM file
   - Add CPL file
   - Click "Process BOM & CPL"

6. **Review Component Matching:**
   - Verify all parts matched
   - Fix any unmatched (search LCSC)
   - Note any shortages

7. **Component Placement Preview:**
   - Check component positions
   - Adjust rotations if needed
   - Confirm polarized components correct

8. **Review Quote:**
   - PCB cost
   - Assembly cost
   - Component cost
   - Shipping cost
   - Total

9. **Place Order:**
   - Add to cart
   - Complete checkout

### Step 6: Save Order Information

Create `process/reviews/PRR.md`:

```markdown
# Production Readiness Review

## Order Details
- Order Number: [JLCPCB order number]
- Order Date: [date]
- Quantity: [PCB qty] PCBs, [PCBA qty] assembled

## Costs
| Item | Cost |
|------|------|
| PCB fabrication | $ |
| Assembly | $ |
| Components | $ |
| Shipping | $ |
| **Total** | $ |

## Component Status
- All matched: [Yes/No]
- Substitutions: [list]
- Shortages: [list]

## Expected Delivery
- Production: [X] days
- Shipping: [X] days
- Estimated arrival: [date]

## Files Submitted
- Gerbers: gerbers.zip (SHA256: [hash])
- BOM: bom.csv
- CPL: positions.csv

## Approval
- Approved by: [name]
- Date: [date]
```

### Step 7: Track Order

JLCPCB order status stages:
1. Payment confirmed
2. PCB in production
3. PCB completed
4. Assembly in progress
5. Assembly completed
6. QC passed
7. Shipped
8. Delivered

## Common Issues

| Issue | Cause | Fix |
|---|---|-----|
| Gerber rejected | Missing layers | Regenerate with all layers |
| BOM mismatch | Wrong format | Use JLCPCB template |
| Part not found | Wrong LCSC number | Search LCSC directly |
| Rotation wrong | CPL offset | Adjust rotation in JLCPCB |
| Part out of stock | Stock changed | Find alternative |

## Output Summary

```
## Manufacturing Files Generated

### Files Created
- production/gerbers.zip
- production/bom.csv
- production/positions.csv

### Next Steps
1. Upload to JLCPCB
2. Configure order options
3. Review and confirm
4. Complete payment

### Order Tracking
Order submitted: [Yes/No]
Order number: [number]
Expected arrival: [date]
```

## Success Criteria

- [ ] Gerbers generated and verified
- [ ] BOM in JLCPCB format
- [ ] CPL in JLCPCB format
- [ ] Order placed successfully
- [ ] Order number recorded

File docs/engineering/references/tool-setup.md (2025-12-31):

# Tool Setup

Last Updated: December 30, 2025

## KiCad

- **Version:** 9.0.6
- **Location:** `/usr/local/bin/kicad-cli`
- **IPC API:** Enabled (required for MCP server)

## Python Virtual Environment

All Python packages installed in `venv/`:

```bash
source venv/bin/activate
```

### Installed Packages

| Package | Version | Purpose |
|---|---|---|
| kicad-python | 0.5.0 | Official IPC API bindings |
| kigadgets | 0.5.1 | Cross-version KiCad compatibility |
| skidl | 2.2.1 | Code-first schematic design |
| kibot | 1.8.5 | CI/CD automation, fabrication files |
| kiauto | 2.3.5 | KiCad automation scripts |
| easyeda2kicad | 0.8.0 | Import LCSC/EasyEDA components |
| interactivehtmlbom | 2.10.0 | Interactive assembly BOM |
| kicad-parts-placer | 0.1.4 | Component placement from centroid |

## System Tools

| Tool | Version | Purpose |
|---|---|---|
| gerbv | 2.10.0 | Gerber file viewer/export |

## Not Yet Installed

- [ ] FreeRouting JAR (auto-router) - Download from GitHub releases
- [ ] kicad-mcp-python (MCP server) - Clone and configure

## Tool Locations

```
venv/bin/
├── python3           # Python interpreter
├── pip               # Package installer
├── kibot             # KiBot CLI
├── easyeda2kicad     # Component importer
├── generate_interactive_bom  # Interactive BOM
└── ...

/usr/local/bin/
└── kicad-cli         # KiCad CLI

/opt/homebrew/bin/
└── gerbv             # Gerber viewer
```

## Activation

```bash
cd /Users/zeul/GIT/singingcard
source venv/bin/activate
```

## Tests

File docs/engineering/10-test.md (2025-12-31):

# PCB Test & Verification

Phase 11 of PCB Systems Engineering Lifecycle.

## Activation
- User says: /pcb-test, test board, verify pcb, bring up
- After boards received from manufacturing

## Purpose

Verify manufactured PCBs meet requirements through systematic testing.

## Prerequisites

- PCBs received from JLCPCB
- Test equipment available
- Requirements Traceability Matrix (RTM) ready

## Test Levels

Following V-Model, testing proceeds from component to system level:

```
Requirements ◄─────────────────────────────► Acceptance Test
     │                                              ▲
     ▼                                              │
System Design ◄────────────────────────────► System Test
     │                                              ▲
     ▼                                              │
Subsystem Design ◄─────────────────────────► Integration Test
     │                                              ▲
     ▼                                              │
Component Design ◄─────────────────────────► Unit Test
```

## Process

### Step 1: Incoming Inspection

**Visual Inspection Checklist:**
- [ ] Correct quantity received
- [ ] Board dimensions match design
- [ ] No visible damage (cracks, scratches)
- [ ] Solder mask intact
- [ ] Silkscreen legible
- [ ] Copper traces clean (no shorts/opens visible)
- [ ] Components present (if assembled)
- [ ] Component orientation correct
- [ ] Solder joints acceptable

**Take photos and save to `tmp/inspection/`**

**Defects Found:**
| Item | Location | Severity | Action |
|---|---|---|---|
| | | | |

### Step 2: Bare Board Testing (if applicable)

If boards are not assembled:

**Continuity Testing:**
- [ ] Power rails continuous end-to-end
- [ ] No shorts between VCC and GND
- [ ] Critical signal paths continuous

**Isolation Testing:**
- [ ] Power rails isolated from each other
- [ ] Signal paths isolated from power

### Step 3: Power-On Test (First Article)

**CRITICAL: Use current-limited power supply**

**Pre-Power Checklist:**
- [ ] Visual inspection complete
- [ ] No obvious shorts
- [ ] Correct polarity marked
- [ ] Current limit set (50-100mA initially)

**Power-On Procedure:**
1. Connect current-limited supply
2. Set voltage to minimum, slowly increase to nominal
3. Monitor current draw
4. Check for:
   - Smoke or burning smell (STOP immediately)
   - Excessive current (compare to expected)
   - Correct voltage at test points
   - No hot components

**Initial Power Measurements:**
| Measurement | Expected | Actual | Status |
|---|---|---|---|
| Input current (idle) | | | |
| VCC voltage | | | |
| 3V3 rail (if present) | | | |
| Current (active) | | | |

### Step 4: Unit Testing

Test individual functional blocks:

**Power Supply:**
- [ ] Input voltage range
- [ ] Output voltage accuracy
- [ ] Load regulation
- [ ] Ripple voltage (if measurable)

**Microcontroller/IC:**
- [ ] Oscillator running (scope on XTAL)
- [ ] Reset behavior
- [ ] I/O pins toggle correctly
- [ ] Programming interface works

**Communication Interfaces:**
- [ ] SPI/I2C signals present
- [ ] Correct timing (if scope available)
- [ ] Device responds to commands

**Sensors:**
- [ ] Responds to stimulus
- [ ] Values in expected range

**Output Devices:**
- [ ] LED illuminates
- [ ] Speaker produces sound
- [ ] Motor runs (if applicable)

### Step 5: Integration Testing

Test interactions between subsystems:

**Test Cases:**
| ID | Description | Steps | Expected Result | Actual | Status |
|----|---|---|---|---|---|
| IT-001 | | | | | |
| IT-002 | | | | | |

### Step 6: System Testing

Test complete system operation:

**Functional Tests:**
Map to Functional Requirements (FR-xxx):

| Req ID | Requirement | Test Method | Result | Status |
|---|---|---|---|---|
| FR-001 | | | | |
| FR-002 | | | | |

**Performance Tests:**
Map to Performance Requirements (PR-xxx):

| Req ID | Requirement | Test Method | Target | Result | Status |
|---|---|---|---|---|---|
| PR-001 | | | | | |

### Step 7: Environmental Testing (If Required)

**Temperature Testing:**
- [ ] Function at minimum temperature
- [ ] Function at maximum temperature
- [ ] No damage after temperature cycling

**Other Environmental:**
- [ ] Humidity (if specified)
- [ ] Vibration (if specified)
- [ ] Drop test (if specified)

### Step 8: Acceptance Testing

Final verification against all requirements:

**Update Requirements Traceability Matrix:**

| Req ID | Verified | Method | Evidence | Date |
|---|---|---|---|---|
| FR-001 | Yes/No | T/A/I/D | | |
| FR-002 | Yes/No | T/A/I/D | | |

**Verification Methods:**
- T = Test (measured)
- A = Analysis (calculated)
- I = Inspection (visual)
- D = Demonstration (observed)

### Step 9: Document Results

Create Test Report `process/reviews/TEST-REPORT.md`:

```markdown
# Test Report: [Project Name]

## Summary
- Test Date: [date]
- Tester: [name]
- Units Tested: [count]
- Pass: [count]
- Fail: [count]

## Test Configuration
- Power Supply: [model]
- Multimeter: [model]
- Other Equipment: [list]

## Results Summary

### Functional Requirements
| Req ID | Result |
|--------|--------|
| FR-001 | PASS/FAIL |

### Performance Requirements
| Req ID | Target | Result | Status |
|--------|--------|--------|--------|
| PR-001 | | | PASS/FAIL |

## Defects Found
| ID | Description | Severity | Resolution |
|----|-------------|----------|------------|
| | | | |

## Conclusions
[Summary of test results and recommendations]

## Approval
- Tested by: [name]
- Reviewed by: [name]
- Date: [date]
```

### Step 10: Lessons Learned

Document improvements for next revision:

```markdown
## Lessons Learned

### What Worked Well
1.
2.

### What Could Be Improved
1.
2.

### Design Changes for Next Revision
1.
2.
```

## Test Equipment Recommendations

| Equipment | Purpose | Minimum Spec |
|---|---|---|
| Multimeter | Voltage, current, resistance | 3.5 digit |
| Power Supply | Controlled power | Current limiting |
| Oscilloscope | Signal analysis | 50MHz, 2ch |
| Logic Analyzer | Digital debug | 8ch, 24MHz |
| Programmer | MCU programming | Device-specific |

## Common First-Board Issues

| Symptom | Likely Cause | Check |
|---|---|---|
| No power | Solder bridge, open | Visual, continuity |
| High current | Short circuit | Remove ICs, test rails |
| Chip hot | Wrong orientation | Check pin 1 |
| No clock | Crystal circuit | ESR of caps, layout |
| SPI/I2C fail | Wrong pull-ups | Signal integrity |
| Noise | Decoupling | Add/improve caps |

## Output Summary

```
## Testing Complete

### Results
- Units tested: [count]
- Passed: [count]
- Failed: [count]

### Requirements Verification
- Functional: [X]/[Y] passed
- Performance: [X]/[Y] met
- Overall: [PASS/CONDITIONAL/FAIL]

### Next Steps
[ ] Project complete - celebrate!
[ ] Minor fixes - create issue list
[ ] Major rework - plan revision

### Documentation
- Test report: process/reviews/TEST-REPORT.md
- RTM updated: requirements/RTM.md
- Lessons learned: process/reviews/LESSONS-LEARNED.md
```

## Success Criteria

- [ ] All units inspected
- [ ] Power-on test completed
- [ ] All requirements verified
- [ ] Test report documented
- [ ] Defects logged
- [ ] Lessons learned captured

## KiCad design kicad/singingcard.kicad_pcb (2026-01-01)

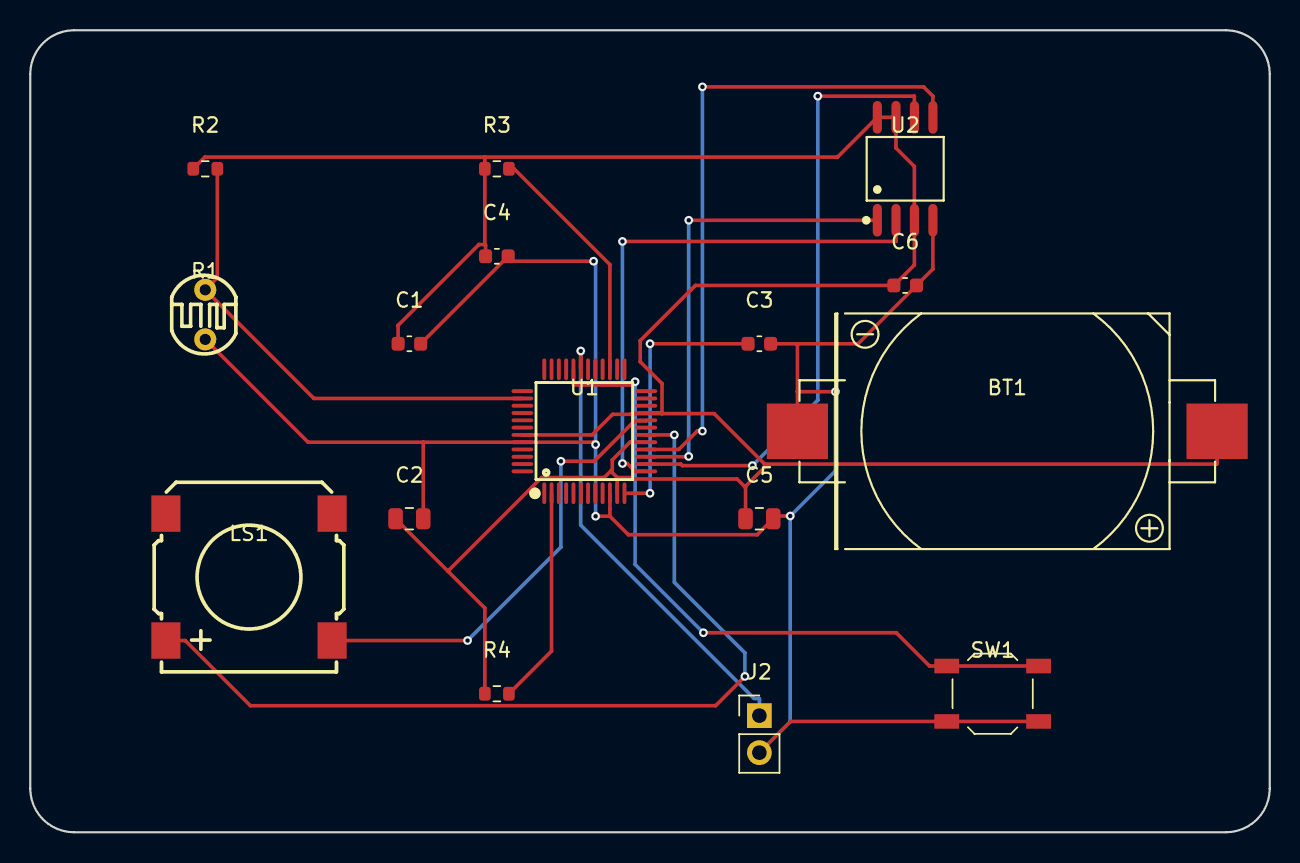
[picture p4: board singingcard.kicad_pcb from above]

Board: 2 copper layers, 85.0 x 55.0 mm, 16 parts (0 on the bottom side), 14 nets.

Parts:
BT1: CR2032; BAT-TH_CR2032-BS-6-1
C1, C4, C6: 100nF; C_0603_1608Metric
C2, C5: 10uF; C_0805_2012Metric
C3: 1uF; C_0603_1608Metric
J2: Pull-Tab; PinHeader_1x02_P2.54mm_Vertical
LS1: KLJ-01304T-08R07W; BUZ-SMD_4P-L13.0-W13.0-P11.4-BL
R1: GL5528; RES-TH_L5.1-W4.3-P3.40-D0.5
R2, R3, R4: 10k; R_0603_1608Metric
SW1: Button; SW_SPST_TL3342
U1: ISD3900FYI; LQFP-48_L7.0-W7.0-P0.50-LS9.0-BL
U2: W25Q16JVSSIQ; SOIC-8_L5.3-W5.3-P1.27-LS8.0-BL

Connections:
+3V: BT1.1, C1.1, C2.1, C4.1, C5.1, C6.1, R2.1, R3.1, R4.1, U1.11, U1.17, U1.21, U1.43, U2.3, U2.7, U2.8
CSB: R4.2, U1.2
GND: BT1.2, C1.2, C2.2, C3.2, C4.2, C5.2, C6.2, J2.2, R1.2, SW1.2, U1.10, U1.44, U2.4
GPIO0_LDR: R1.1, R2.2, U1.38
GPIO1_BTN: SW1.1, U1.32
GPIO2_TAB: J2.1, U1.31
unnamed: LS1.1, U1.18
unnamed: LS1.2, U1.20
RESET: R3.2, U1.27
SPI_CS: U1.15, U2.1
SPI_MISO: U1.13, U2.2
SPI_MOSI: U1.16, U2.5
SPI_SCK: U1.14, U2.6
VREG: C3.1, U1.12

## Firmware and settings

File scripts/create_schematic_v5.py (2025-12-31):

#!/usr/bin/env python3
"""
Create KiCad 9 schematic with proper pin connectivity.
Places global labels directly at pin endpoints.
"""

import uuid
import math

def gen_uuid():
    return str(uuid.uuid4())

# Symbol pin offsets from symbol center
# Format: {symbol_name: {pin_num: (dx, dy, angle)}}
# For ICs: left pins point right (angle=0), right pins point left (angle=180)
# For 2-pin: pin 1 up (270), pin 2 down (90)

def get_ic_pin_positions(num_pins):
    """Get pin positions for IC with given number of pins."""
    half = num_pins // 2
    height = max(10.16, (half + 1) * 2.54)
    width = 15.24
    positions = {}

    # Left side pins (1 to half)
    for i in range(half):
        pin_num = i + 1
        y = height/2 - 2.54 - i * 2.54
        x = -width/2 - 5.08
        positions[str(pin_num)] = (x, y, 0)

    # Right side pins (half+1 to num_pins) - numbered in reverse
    for i in range(half):
        pin_num = num_pins - i
        y = height/2 - 2.54 - i * 2.54
        x = width/2 + 5.08
        positions[str(pin_num)] = (x, y, 180)

    return positions

def get_2pin_positions():
    """Get pin positions for 2-pin symbol."""
    return {
        '1': (0, 5.08, 270),
        '2': (0, -5.08, 90),
    }

def get_speaker_positions():
    """Get pin positions for 4-pin speaker symbol (horizontal layout)."""
    # Matches KLJ-01304T-08R07W: pins 1,2 on left (signal), pins 3,4 on right (dummy)
    return {
        '1': (-12.7, 1.27, 0),    # LEAD+ (left side, top)
        '2': (-12.7, -1.27, 0),   # LEAD- (left side, bottom)
        '3': (12.7, -1.27, 180),  # DUMMY (right side, bottom)
        '4': (12.7, 1.27, 180),   # DUMMY (right side, top)
    }

# Component definitions - compact layout (grid-aligned to 2.54mm)
COMPONENTS = {
    'U1': {
        'name': 'ISD3900FYI',
        'value': 'ISD3900FYI',
        'footprint': 'singingcard:LQFP-48_L7.0-W7.0-P0.50-LS9.0-BL',
        'description': 'Audio record/playback IC',
        'num_pins': 48,
        'position': (76.2, 76.2),  # Center
    },
    'U2': {
        'name': 'W25Q16JVSSIQ',
        'value': 'W25Q16JVSSIQ',
        'footprint': 'singingcard:SOIC-8_L5.3-W5.3-P1.27-LS8.0-BL',
        'description': 'SPI Flash memory',
        'num_pins': 8,
        'position': (139.7, 50.8),  # Right of U1
    },
    'BT1': {
        'name': 'CR2032',
        'value': 'CR2032',
        'footprint': 'singingcard:BAT-TH_CR2032-BS-6-1',
        'description': 'CR2032 battery holder',
        'num_pins': 2,
        'position': (170.18, 76.2),  # Far right
    },
    'R1': {
        'name': 'LDR',
        'value': 'GL5528',
        'footprint': 'singingcard:RES-TH_L5.1-W4.3-P3.40-D0.5',
        'description': 'Light dependent resistor',
        'num_pins': 2,
        'position': (20.32, 30.48),  # Top left row
    },
    'R2': {
        'name': 'R',
        'value': '10k',
        'footprint': 'Resistor_SMD:R_0603_1608Metric',
        'description': 'Resistor',
        'num_pins': 2,
        'position': (33.02, 30.48),
    },
    'R3': {
        'name': 'R',
        'value': '10k',
        'footprint': 'Resistor_SMD:R_0603_1608Metric',
        'description': 'Resistor',
        'num_pins': 2,
        'position': (45.72, 30.48),
    },
    'R4': {
        'name': 'R',
        'value': '10k',
        'footprint': 'Resistor_SMD:R_0603_1608Metric',
        'description': 'Resistor',
        'num_pins': 2,
        'position': (58.42, 30.48),
    },
    'C1': {
        'name': 'C',
        'value': '100nF',
        'footprint': 'Capacitor_SMD:C_0603_1608Metric',
        'description': 'Capacitor',
        'num_pins': 2,
        'position': (20.32, 114.3),  # Bottom row
    },
    'C2': {
        'name': 'C',
        'value': '100nF',
        'footprint': 'Capacitor_SMD:C_0603_1608Metric',
        'description': 'Capacitor',
        'num_pins': 2,
        'position': (33.02, 114.3),
    },
    'C3': {
        'name': 'C',
        'value': '100nF',
        'footprint': 'Capacitor_SMD:C_0603_1608Metric',
        'description': 'Capacitor',
        'num_pins': 2,
        'position': (45.72, 114.3),
    },
    'C4': {
        'name': 'C',
        'value': '10uF',
        'footprint': 'Capacitor_SMD:C_0805_2012Metric',
        'description': 'Capacitor',
        'num_pins': 2,
        'position': (58.42, 114.3),
    },
    'C5': {
        'name': 'C',
        'value': '10uF',
        'footprint': 'Capacitor_SMD:C_0805_2012Metric',
        'description': 'Capacitor',
        'num_pins': 2,
        'position': (71.12, 114.3),
    },
    'C6': {
        'name': 'C',
        'value': '100nF',
        'footprint': 'Capacitor_SMD:C_0603_1608Metric',
        'description': 'Capacitor',
        'num_pins': 2,
        'position': (160.02, 50.8),  # Near U2
    },
    'LS1': {
        'name': 'Speaker',
        'value': 'KLJ-01304T-08R07W',
        'footprint': 'speaker:BUZ-SMD_4P-L13.0-W13.0-P11.4-BL',
        'description': 'SMD Speaker 8ohm 700mW',
        'num_pins': 4,
        'position': (114.3, 30.48),  # Top right
    },
    'J2': {
        'name': 'Conn_01x02',
        'value': 'Audio_In',
        'footprint': 'Connector_PinHeader_2.54mm:PinHeader_1x02_P2.54mm_Vertical',
        'description': 'Audio input connector',
        'num_pins': 2,
        'position': (20.32, 76.2),  # Left of U1
    },
    'SW1': {
        'name': 'SW_Push',
        'value': 'Button',
        'footprint': 'Button_Switch_SMD:SW_SPST_TL3342',
        'description': 'Push button switch',
        'num_pins': 2,
        'position': (20.32, 53.34),  # Left side
    },
}

# Net connections (ref, pin) pairs
NETS = {
    '+3V': [('BT1', '1'), ('U1', '10'), ('U1', '11'), ('U1', '20'), ('U2', '8'),
            ('C1', '1'), ('C2', '1'), ('C3', '1'), ('C4', '1'), ('C5', '1'), ('C6', '1'),
            ('R2', '1'), ('R3', '1'), ('R4', '1'), ('U2', '3'), ('U2', '7')],
    'GND': [('BT1', '2'), ('U1', '16'), ('U2', '4'),
            ('C1', '2'), ('C2', '2'), ('C3', '2'), ('C4', '2'), ('C5', '2'), ('C6', '2'),
            ('R1', '2'), ('SW1', '2')],
    'GPIO0': [('U1', '21'), ('R1', '1'), ('R2', '2')],
    'GPIO1': [('U1', '27'), ('SW1', '1')],
    'GPIO2': [('U1', '31'), ('R3', '2')],
    'RESET': [('U1', '12'), ('R4', '2')],
    'SPI_CS': [('U1', '38'), ('U2', '1')],
    'SPI_MOSI': [('U1', '43'), ('U2', '5')],
    'SPI_MISO': [('U1', '44'), ('U2', '2')],
    'SPI_CLK': [('U1', '32'), ('U2', '6')],
    'SP+': [('U1', '17'), ('LS1', '1')],
    'SP-': [('U1', '18'), ('LS1', '2')],
    'ANA_IN+': [('U1', '14'), ('J2', '1')],
    'ANA_IN-': [('U1', '15'), ('J2', '2')],
}

# NC pins for U1 (not connected to any net)
NC_PINS_U1 = ['1', '2', '3', '4', '5', '6', '7', '8', '9', '13', '19', '22', '23', '24', '25', '26',
              '28', '29', '30', '33', '34', '35', '36', '37', '39', '40', '41', '42', '45', '46', '47', '48']

def get_pin_world_position(ref, pin_num):
    """Get world position of a pin."""
    comp = COMPONENTS[ref]
    cx, cy = comp['position']

    if comp['name'] == 'Speaker':
        pin_offsets = get_speaker_positions()
    elif comp['num_pins'] == 2:
        pin_offsets = get_2pin_positions()
    else:
        pin_offsets = get_ic_pin_positions(comp['num_pins'])

    if pin_num in pin_offsets:
        dx, dy, angle = pin_offsets[pin_num]
        return (cx + dx, cy + dy, angle)
    return None

def create_lib_symbols():
    """Create embedded symbol definitions."""
    symbols = []

    # Create IC symbols
    symbols.append(create_ic_symbol('singingcard:ISD3900FYI', 48, 'U'))
    symbols.append(create_ic_symbol('singingcard:W25Q16JVSSIQ', 8, 'U'))

    # Create 2-pin symbols
    for name in ['CR2032', 'LDR', 'R', 'C', 'Conn_01x02', 'SW_Push']:
        ref = 'BT' if name == 'CR2032' else ('R' if name in ['LDR', 'R'] else ('C' if name == 'C' else ('J' if name == 'Conn_01x02' else 'SW')))
        symbols.append(create_2pin_symbol(f'singingcard:{name}', ref))

    # Create 4-pin speaker symbol
    symbols.append(create_speaker_symbol('singingcard:Speaker', 'LS'))

    return '\n'.join(symbols)

def create_speaker_symbol(name, ref_prefix):
    """Create 4-pin speaker symbol matching KLJ-01304T-08R07W."""
    sym = f'''		(symbol "{name}"
			(pin_names
				(offset 1.016)
			)
			(exclude_from_sim no)
			(in_bom yes)
			(on_board yes)
			(property "Reference" "{ref_prefix}"
				(at 0 6.35 0)
				(effects
					(font
						(size 1.27 1.27)
					)
				)
			)
			(property "Value" "{name.split(':')[1]}"
				(at 0 -6.35 0)
				(effects
					(font
						(size 1.27 1.27)
					)
				)
			)
			(property "Footprint" ""
				(at 0 0 0)
				(effects
					(font
						(size 1.27 1.27)
					)
					(hide yes)
				)
			)
			(property "Datasheet" ""
				(at 0 0 0)
				(effects
					(font
						(size 1.27 1.27)
					)
					(hide yes)
				)
			)
			(symbol "{name.split(':')[1]}_1_1"
				(rectangle
					(start -10.16 3.81)
					(end 10.16 -3.81)
					(stroke
						(width 0.254)
						(type default)
					)
					(fill
						(type background)
					)
				)
				(pin passive line
					(at -12.7 1.27 0)
					(length 2.54)
					(name "LEAD+"
						(effects
							(font
								(size 1.27 1.27)
							)
						)
					)
					(number "1"
						(effects
							(font
								(size 1.27 1.27)
							)
						)
					)
				)
				(pin passive line
					(at -12.7 -1.27 0)
					(length 2.54)
					(name "LEAD-"
						(effects
							(font
								(size 1.27 1.27)
							)
						)
					)
					(number "2"
						(effects
							(font
								(size 1.27 1.27)
							)
						)
					)
				)
				(pin passive line
					(at 12.7 -1.27 180)
					(length 2.54)
					(name "DUMMY"
						(effects
							(font
								(size 1.27 1.27)
							)
						)
					)
					(number "3"
						(effects
							(font
								(size 1.27 1.27)
							)
						)
					)
				)
				(pin passive line
					(at 12.7 1.27 180)
					(length 2.54)
					(name "DUMMY"
						(effects
							(font
								(size 1.27 1.27)
							)
						)
					)
					(number "4"
						(effects
							(font
								(size 1.27 1.27)
							)
						)
					)
				)
			)
		)'''
    return sym

def create_ic_symbol(name, num_pins, ref_prefix):
    """Create IC symbol with pins."""
    half = num_pins // 2
    height = max(10.16, (half + 1) * 2.54)
    width = 15.24

    sym = f'''		(symbol "{name}"
			(pin_names
				(offset 1.016)
			)
			(exclude_from_sim no)
			(in_bom yes)
			(on_board yes)
			(property "Reference" "{ref_prefix}"
				(at 0 {height/2 + 2.54:.2f} 0)
				(effects
					(font
						(size 1.27 1.27)
					)
				)
			)
			(property "Value" "{name.split(':')[1]}"
				(at 0 {-height/2 - 2.54:.2f} 0)
				(effects
					(font
						(size 1.27 1.27)
					)
				)
			)
			(property "Footprint" ""
				(at 0 0 0)
				(effects
					(font
						(size 1.27 1.27)
					)
					(hide yes)
				)
			)
			(property "Datasheet" ""
				(at 0 0 0)
				(effects
					(font
						(size 1.27 1.27)
					)
					(hide yes)
				)
			)
			(symbol "{name.split(':')[1]}_1_1"
				(rectangle
					(start {-width/2:.2f} {height/2:.2f})
					(end {width/2:.2f} {-height/2:.2f})
					(stroke
						(width 0.254)
						(type default)
					)
					(fill
						(type background)
					)
				)
'''

    # Add pins
    for i in range(half):
        pin_num = i + 1
        y = height/2 - 2.54 - i * 2.54
        x = -width/2 - 5.08
        sym += f'''				(pin passive line
					(at {x:.2f} {y:.2f} 0)
					(length 5.08)
					(name "{pin_num}"
						(effects
							(font
								(size 1.27 1.27)
							)
						)
					)
					(number "{pin_num}"
						(effects
							(font
								(size 1.27 1.27)
							)
						)
					)
				)
'''

    for i in range(half):
        pin_num = num_pins - i
        y = height/2 - 2.54 - i * 2.54
        x = width/2 + 5.08
        sym += f'''				(pin passive line
					(at {x:.2f} {y:.2f} 180)
					(length 5.08)
					(name "{pin_num}"
						(effects
							(font
								(size 1.27 1.27)
							)
						)
					)
					(number "{pin_num}"
						(effects
							(font
								(size 1.27 1.27)
							)
						)
					)
				)
'''

    sym += '''			)
		)'''
    return sym

def create_2pin_symbol(name, ref_prefix):
    """Create 2-pin symbol."""
    sym = f'''		(symbol "{name}"
			(pin_names
				(offset 1.016)
				(hide yes)
			)
			(exclude_from_sim no)
			(in_bom yes)
			(on_board yes)
			(property "Reference" "{ref_prefix}"
				(at 2.54 0 0)
				(effects
					(font
						(size 1.27 1.27)
					)
					(justify left)
				)
			)
			(property "Value" "{name.split(':')[1]}"
				(at 2.54 -2.54 0)
				(effects
					(font
						(size 1.27 1.27)
					)
					(justify left)
				)
			)
			(property "Footprint" ""
				(at 0 0 0)
				(effects
					(font
						(size 1.27 1.27)
					)
					(hide yes)
				)
			)
			(property "Datasheet" ""
				(at 0 0 0)
				(effects
					(font
						(size 1.27 1.27)
					)
					(hide yes)
				)
			)
			(symbol "{name.split(':')[1]}_1_1"
				(rectangle
					(start -1.27 2.54)
					(end 1.27 -2.54)
					(stroke
						(width 0.254)
						(type default)
					)
					(fill
						(type none)
					)
				)
				(pin passive line
					(at 0 5.08 270)
					(length 2.54)
					(name "1"
						(effects
							(font
								(size 1.27 1.27)
							)
						)
					)
					(number "1"
						(effects
							(font
								(size 1.27 1.27)
							)
						)
					)
				)
				(pin passive line
					(at 0 -5.08 90)
					(length 2.54)
					(name "2"
						(effects
							(font
								(size 1.27 1.27)
							)
						)
					)
					(number "2"
						(effects
							(font
								(size 1.27 1.27)
							)
						)
					)
				)
			)
		)'''
    return sym

def create_symbol_instance(ref, comp, project_uuid):
    """Generate symbol instance."""
    x, y = comp['position']
    lib_name = f"singingcard:{comp['name']}"
    comp_uuid = gen_uuid()

    # Get list of pins
    pins = [str(i) for i in range(1, comp['num_pins'] + 1)]

    # For 2-pin and speaker components, place reference/value appropriately
    if comp['num_pins'] == 2 or comp['name'] == 'Speaker':
        ref_x, ref_y, ref_angle = x + 5.08, y, 0
        val_x, val_y, val_angle = x + 5.08, y + 2.54, 0
        ref_justify = '\n\t\t\t\t\t(justify left)'
        val_justify = '\n\t\t\t\t\t(justify left)'
    else:
        ref_x, ref_y, ref_angle = x, y - 12, 0
        val_x, val_y, val_angle = x, y - 15, 0
        ref_justify = ''
        val_justify = ''

    sym = f'''	(symbol
		(lib_id "{lib_name}")
		(at {x} {y} 0)
		(unit 1)
		(exclude_from_sim no)
		(in_bom yes)
		(on_board yes)
		(dnp no)
		(uuid "{comp_uuid}")
		(property "Reference" "{ref}"
			(at {ref_x} {ref_y} {ref_angle})
			(effects
				(font
					(size 1.27 1.27)
				){ref_justify}
			)
		)
		(property "Value" "{comp['value']}"
			(at {val_x} {val_y} {val_angle})
			(effects
				(font
					(size 1.27 1.27)
				){val_justify}
			)
		)
		(property "Footprint" "{comp['footprint']}"
			(at {x} {y} 0)
			(effects
				(font
					(size 1.27 1.27)
				)
				(hide yes)
			)
		)
		(property "Datasheet" ""
			(at {x} {y} 0)
			(effects
				(font
					(size 1.27 1.27)
				)
				(hide yes)
			)
		)
		(property "Description" "{comp['description']}"
			(at {x} {y} 0)
			(effects
				(font
					(size 1.27 1.27)
				)
				(hide yes)
			)
		)
'''
    for pin in pins:
        sym += f'''		(pin "{pin}"
			(uuid "{gen_uuid()}")
		)
'''

    sym += f'''		(instances
			(project "singingcard"
				(path "/{project_uuid}"
					(reference "{ref}")
					(unit 1)
				)
			)
		)
	)
'''
    return sym

def create_global_label_with_wire(net_name, x, y, angle=0, pin_num=0):
    """Generate global label offset from pin position with connecting wire.

    Pin angle indicates direction pin BODY extends FROM connection point TOWARD component:
    - 0: pin body extends right (pin is on left side of IC)
    - 180: pin body extends left (pin is on right side of IC)
    - 90: pin body extends down in screen coords (pin is at top of 2-pin component)
    - 270: pin body extends up in screen coords (pin is at bottom of 2-pin component)

    Label is placed OPPOSITE to pin body direction (away from component).
    Label arrow points toward pin (same as pin angle).
    Wire connects pin to label.
    """
    # Place label directly at pin position - no wire needed
    # KiCad global labels connect at their position
    label_x = x
    label_y = y

    # Label angle determines which way the label BODY extends FROM the connection point
    # In KiCad: angle is the direction the label text/flag extends
    # - angle 0: label extends to the RIGHT of connection point
    # - angle 180: label extends to the LEFT of connection point
    # - angle 90: label extends DOWN
    # - angle 270: label extends UP
    # We want label to extend AWAY from the component
    # Pin angle indicates direction toward component, so label should extend OPPOSITE
    if angle == 0:
        label_angle = 180  # Left side IC pins - arrow points left, text extends right
    elif angle == 180:
        label_angle = 0    # Right side IC pins - arrow points right, text extends left
    elif angle == 90:
        label_angle = 270  # Pin body goes down, label extends UP
    elif angle == 270:
        label_angle = 90   # Pin body goes up, label extends DOWN
    else:
        label_angle = (int(angle) + 180) % 360

    # No wire needed - label connects directly at pin position
    wire = ''

    # Labels extending left (180) or down (90) use justify right
    # Labels extending right (0) or up (270) use justify left
    justify = 'right' if label_angle in [90, 180] else 'left'

    label = f'''	(global_label "{net_name}"
		(shape input)
		(at {label_x:.2f} {label_y:.2f} {label_angle})
		(fields_autoplaced yes)
		(effects
			(font
				(size 1.27 1.27)
			)
			(justify {justify})
		)
		(uuid "{gen_uuid()}")
		(property "Intersheetrefs" "${{INTERSHEET_REFS}}"
			(at {label_x:.2f} {label_y:.2f} 0)
			(effects
				(font
					(size 1.27 1.27)
				)
				(hide yes)
			)
		)
	)
'''
    return wire + label

def create_no_connect(x, y):
    """Generate no-connect flag at exact position."""
    return f'''	(no_connect
		(at {x:.2f} {y:.2f})
		(uuid "{gen_uuid()}")
	)
'''

def main():
    print("Creating KiCad 9 schematic with proper connectivity...")

    project_uuid = gen_uuid()

    # Header
    sch = f'''(kicad_sch
	(version 20250114)
	(generator "create_schematic_v5.py")
	(generator_version "9.0")
	(uuid "{project_uuid}")
	(paper "A5")
	(title_block
		(title "Singing Birthday Card Module")
		(date "2025-12-30")
		(rev "1.0")
		(comment 1 "ISD3900FYI Audio Playback")
		(comment 2 "CR2032 Powered, SPI Flash Storage")
	)
	(lib_symbols
{create_lib_symbols()}
	)

'''

    # Add symbol instances
    for ref, comp in COMPONENTS.items():
        sch += create_symbol_instance(ref, comp, project_uuid)

    # Add global labels at pin locations with connecting wires
    labels_added = 0
    for net_name, connections in NETS.items():
        for ref, pin in connections:
            if ref in COMPONENTS:
                pos = get_pin_world_position(ref, pin)
                if pos:
                    x, y, angle = pos
                    pin_num = int(pin) if pin.isdigit() else 0
                    sch += create_global_label_with_wire(net_name, x, y, angle, pin_num)
                    labels_added += 1

    # Add no-connects at NC pin locations
    nc_added = 0
    for pin in NC_PINS_U1:
        pos = get_pin_world_position('U1', pin)
        if pos:
            x, y, angle = pos
            sch += create_no_connect(x, y)
            nc_added += 1

    sch += ')\n'

    with open('singingcard.kicad_sch', 'w') as f:
        f.write(sch)

    print(f"Created singingcard.kicad_sch")
    print(f"  - {len(COMPONENTS)} components")
    print(f"  - {labels_added} global labels")
    print(f"  - {nc_added} no-connect flags")

if __name__ == '__main__':
    main()

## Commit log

2025-12-31 Initial setup: KiCad agent workflow for autonomous PCB design
    - Research document with comprehensive tool analysis
    - Claude skill for PCB design workflow
    - Tool setup documentation
    - Workflow quick reference
    - Python venv with kicad-python, skidl, kibot, easyeda2kicad
2025-12-31 Add PCB requirements gathering skill
    Thorough interview process covering:
    - Project overview & purpose
    - Core components (MCU, wireless, sensors)
    - Power requirements
    - I/O & interfaces
    - Physical constraints
    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
2025-12-31 WIP: Singing birthday card module requirements
    Gathered requirements:
    - MP3 playback with USB upload
    - CR2032 battery powered
    - Light/button/pull-tab triggers (jumper selectable)
    - ~85x55mm board, green PCB
    - Target <$3/unit
2025-12-31 Add component research and selection for singing card module
    - Created kicad/component-selection.md with full research
    - Selected ISD3900FYI as audio IC (works with 3V CR2032)
    - Identified W25Q16 SPI flash for audio storage
    - Found GL5528 LDR, CR2032 holder on LCSC/JLCPCB
    - Dropped USB requirement (not available on LCSC)
    - Updated currently-working.md with current status
    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
2025-12-31 Add PCB generation from SKiDL netlist
    - Created schematic netlist using SKiDL with all components
    - Imported LCSC components with easyeda2kicad (upgraded to KiCad 9)
    - Generated PCB file with component placement
    - Added 3D renders for visual debugging
    Components: ISD3900FYI, W25Q16JVSSIQ, GL5528 LDR, CR2032 holder,
    6x capacitors, 4x resistors, 2x headers, tactile switch
    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
    [singingcard.kicad_pcb, singingcard.kicad_sch]
2025-12-31 Add DSN export for FreeRouting auto-routing
    - Created DSN exporter script for Specctra format
    - Downloaded FreeRouting 2.0.1 for auto-routing
    - Fixed net association parsing in PCB file
    14 nets ready for routing
    [singingcard.dsn]
2025-12-31 Add KiCad image export workflow
    Automatically exports schematic SVG, PCB SVGs, 3D renders, and STEP model
    when KiCad files are changed.
2025-12-31 PCB routed: All nets connected, DRC clean
    - Fixed export_dsn.py to use actual pad sizes (was using 600x600um for all)
    - Improved component placement for better routing clearance
    - FreeRouting now routes cleanly with correct pad keepouts
    - 188 track segments, 17 vias, 0 unconnected items
    - Only cosmetic violations remain (silkscreen overlap)
    Key learnings added to kicad-agent.md skill file:
    - DSN export must include proper pad sizes per footprint
    - Correct pad size is critical for FreeRouting clearance
    - Java 21 required for FreeRouting 2.0.1
    [singingcard.dsn, singingcard.kicad_pcb]
2025-12-31 Update kicad-agent skill with critical DSN/routing learnings
    Key additions:
    - DSN export MUST use actual pad sizes per footprint
    - FreeRouting requires Java 21 on macOS
    - Use -mt 1 flag for single-threaded routing (avoids bugs)
    - Added troubleshooting for shorts caused by incorrect pad sizes
    - Component placement spacing guidelines
2025-12-31 Add JLCPCB fabrication files
    Design verified against JLCPCB capabilities:
    - Trace width: 0.25mm (min: 0.127mm/5mil)
    - Trace clearance: 0.2mm (min: 0.127mm/5mil)
    - Via: 0.6mm pad, 0.3mm drill (meets 2-layer min)
    - Board size: 85x55mm (within 5x5mm to 400x500mm)
    Files included:
    - Gerber ZIP with all required layers
    - Drill file (Excellon, mm units)
    - Position file for SMT assembly (CSV)
    - BOM with LCSC part numbers
    [singingcard-B_Courtyard.gbr, singingcard-B_Cu.gbl, singingcard-B_Fab.gbr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]
2025-12-31 Update KiCad images
    [board.step]
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2025-12-31 Add proper KiCad schematic with embedded symbols
    - Created schematic generator scripts (v1-v5) to programmatically
    create KiCad schematics from SKiDL netlist data
    - Final version (v5) places global labels at correct pin positions
    - All 50 ERC violations are warnings (library config), not errors
    - Updated kicad-agent.md skill with V-Model workflow approach
    - Added render images for visual inspection
    - Added DRC and ERC report files
    [singingcard.dsn, singingcard.kicad_sch, singingcard_routed.kicad_pcb]
2025-12-31 Complete schematic/ERC/DRC workflow and generate fab files
    - Fixed schematic generator to use correct footprint names
    - Created local symbol and footprint libraries
    - ERC: 12 warnings (library config), 0 errors
    - DRC: 26 warnings (cosmetic), 0 errors, 0 unconnected
    - PCB fully routed with 188 tracks and vias
    - Generated Gerber, drill, and position files for JLCPCB
    - Created JLCPCB-ready zip file
    - Updated skill file with ERC/DRC severity guidance
    - Added final renders for visual inspection
    [singingcard-B_Courtyard.gbr, singingcard-B_Cu.gbl, singingcard-B_Fab.gbr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]
2025-12-31 Add SMD speaker, fix component placement, clean up renders
    - Replace J1 connector with LS1 SMD speaker (KLJ-01304T-08R07W, LCSC C18186315)
    - Move U2 and C6 outside battery holder area to prevent overlap
    - Move battery holder to meet 0.5mm edge clearance requirement
    - Re-route PCB with FreeRouting (181 tracks, 21 vias)
    - DRC passes with 0 errors, 0 unconnected items
    - Change schematic page size from A3 to A4
    - Clean up old render images, keep only current versions
    - Update fabrication files (JLCPCB-ready zip)
    [singingcard-B_Courtyard.gbr, singingcard-B_Cu.gbl, singingcard-B_Fab.gbr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]
2025-12-31 Fix global label orientation and U2 3D model offset
    Schematic label fixes:
    - Fixed label position formula: now uses x + offset*cos(angle) and
    y - offset*sin(angle) to properly offset labels away from components
    - Fixed label angle: now uses (angle + 180) % 360 so arrow points
    toward the pin, not away from it
    - This resolves labels on left side of chips overlapping with pins
    - ERC reduced from 15 to 12 warnings (removed net conflict warnings)
    Footprint fixes:
    - Fixed U2 (W25Q16JVSSIQ) 3D model offset from (1.65, -2.84, 0) to (0, 0, 0)
    - Updated model path to use ${KIPRJMOD} prefix
    Skill file updates:
    - Updated global label orientation section with correct formulas
    - Added "Common mistak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
    [singingcard.kicad_sch]
2025-12-31 Fix global label orientation formula (iteration 2)
    Corrected the label placement formula:
    - Pin angle points TOWARD component body, not away
    - Label offset should be OPPOSITE to pin angle direction
    - X formula: x - offset * cos(angle)
    - Y formula: y - offset * sin(angle)
    - Label angle: same as pin angle (arrow points toward pin)
    Labels now correctly placed:
    - Left-side IC pins: labels to the LEFT, pointing right
    - Right-side IC pins: labels to the RIGHT, pointing left
    - Top 2-pin: labels ABOVE, pointing down
    - Bottom 2-pin: labels BELOW, pointing up
    ERC: 0 errors, 12 warnings (library path warnings only)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
    [singingcard.kicad_sch]
2025-12-31 Improve schematic readability
    Changes:
    - Increased label offset from 5.08mm to 7.62mm for better spacing
    - Moved reference/value for 2-pin components to the right side
    to avoid overlap with top/bottom pin labels
    - Reference designators now clearly visible next to components
    - Labels properly separated from component bodies
    All 2-pin components (R1-R4, C1-C6, SW1, J2, LS1, BT1) now have:
    - Labels above/below for pin connections
    - Reference/value text to the right side
    ERC: 0 errors, 13 warnings (library path warnings only)
    [singingcard.kicad_sch]
2025-12-31 Improve schematic label layout significantly
    Key fixes:
    - Flipped label angles for IC pins (angle 0→180, 180→0)
    so wire connects to label tip, not through label text
    - 4-level stagger for IC labels (pins mod 4) with 12.7mm spacing
    to spread labels horizontally and prevent overlap
    - A3 page size with spread-out component layout
    - Grid-aligned component positions (2.54mm grid)
    Label placement logic:
    - Left-side IC pins: label left of pin, angle 180 (text extends right)
    - Right-side IC pins: label right of pin, angle 0 (text extends left)
    - Stagger offset: 5.08 + (pin_num % 4) * 12.7 mm
    ERC: 0 errors, 12 warnings (library paths only)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
    [singingcard.kicad_sch]
2025-12-31 Fix global label orientation formula (iteration 2)
    - Flip label angle by 180° for IC pins so wires connect to label tip
    - Labels now properly extend away from components, not through them
    - Left-side IC labels use angle 180, right-side use angle 0
    - Reduces ERC violations from 12 to 1 (only Speaker symbol warning)
    [singingcard.kicad_sch]
2025-12-31 Fix global label orientation - flags point toward component
    - Remove incorrect 180° flip from label angle calculation
    - Label flags now point toward component (same direction as pin angle)
    - Left-side pins: flag points right, text extends left
    - Right-side pins: flag points left, text extends right
    - Wires connect to flag tip, not through label text
    [singingcard.kicad_sch]
2025-12-31 Compact schematic layout on A4, labels directly on pins
    - Change from A3 to A4 page size
    - Compact component positions for tighter layout
    - Place labels directly at pin positions (no wires)
    - Label angles opposite to pin direction so text extends away from components
    - Much cleaner appearance without wire-through-label issues
    [singingcard.kicad_sch]
2025-12-31 Use input shape labels with fields_autoplaced
    - Change label shape from bidirectional to input
    - Add fields_autoplaced yes for automatic positioning
    - Add justify left to effects
    - Cleaner arrow-style labels matching KiCad convention
    [singingcard.kicad_sch]
2025-12-31 Rotate left-side IC labels by 180 degrees
    - Left side IC pin labels now use angle 0 (arrow points right)
    - Text extends left, away from the IC body
    [singingcard.kicad_sch]
2025-12-31 Rotate left-side IC labels to angle 0
    - Right side IC pin labels use angle 0 (arrow points right)
    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
    [singingcard.kicad_sch]
2025-12-31 Fix left-side IC label angle to 180
    - Left side IC pins use angle 180 (matching user's GPIO0 fix)
    - Right side IC pins use angle 0
    [singingcard.kicad_sch]
2025-12-31 Ensure all left-side IC labels use angle 180
    [singingcard.kicad_sch]
2025-12-31 All left-side IC labels use angle 180
    Matches user's GPIO0 fix - all left-side IC pin labels now
    consistently use angle 180 for proper orientation.
    [singingcard.kicad_sch]
2025-12-31 Fix global label justify and compact layout
    - Fix label orientation: justify right for angles 90/180, left for 0/270
    - Compact layout on A5 page (was A4)
    - Move components closer together
    [singingcard.kicad_sch]
2025-12-31 Clean up repository
    - Remove old schematic generator versions (keep v5)
    - Remove obsolete DRC/ERC report files
    - Remove old routing scripts and files
    - Remove freerouting.jar and board.step (large binaries)
    - Consolidate images to /images
    - Update .gitignore
    [board.step, singingcard.dsn, singingcard_routed.kicad_pcb]
2025-12-31 Fix CI: allow images/board.step in gitignore
    The export-images workflow exports board.step to images/
    but *.step was globally ignored, causing git add to fail.
2025-12-31 Fix speaker symbol and update schematic
    - Update speaker to 4-pin symbol matching KLJ-01304T-08R07W
    - Add proper pin positions for speaker (LEAD+, LEAD-, DUMMY x2)
    - Fix 3D model path in PCB (use ${KIPRJMOD} variable)
    - Update documentation with current status and routing instructions
    [singingcard.kicad_pcb, singingcard.kicad_sch]
2025-12-31 Route PCB and generate manufacturing files
    - Autoroute PCB using FreeRouting (all nets connected)
    - Generate Gerber files for JLCPCB
    - Generate drill and position files
    - Render 3D board images
    - DRC: 0 unconnected, only minor silk warnings
    [singingcard-B_Courtyard.gbr, singingcard-B_Cu.gbl, singingcard-B_Fab.gbr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]
2025-12-31 Fix U2 3D model path and offset
    - Changed model path to use ${KIPRJMOD} for proper resolution
    - Reset offset from (1.65, -2.84, 0) to (0, 0, 0) matching the original footprint
    [singingcard.kicad_pcb]
2025-12-31 Add KiCad CI debugging skill
    Documents common workflow failures and fixes:
    - Gitignore blocking exported files
    - Race conditions with concurrent runs
    - Debugging commands for GitHub Actions
2025-12-31 Add updated 3D renders and Fabrication Toolkit output
    - Regenerated 3D renders with corrected U2 model position
    - Fabrication Toolkit generated files for JLCPCB order
    [bom.csv, designators.csv, positions.csv]
2025-12-31 Add PCB Systems Engineering process documentation
    Comprehensive systems engineering workflow following NASA/DoD/IEEE
    standards adapted for JLCPCB manufacturing:
    - V-Model lifecycle with 12 phases
    - Review gates: SRR, PDR, CDR, PRR
    - Directory structure standard
    - Required documents: PRD, ConOps, ICD, RTM
    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
2025-12-31 Add tooling wishlist for KiCad integration
    Documents tools that would improve Claude Code's PCB workflow:
    - KiCad Python Bridge (MCP Server) - highest priority
    - JLCPCB Parts API client
    - Gerber analyzer/validator
    - Headless render server
    - Schematic generator library
    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
2025-12-31 Update tooling wishlist with kicad-cli capabilities
    - Added "Already Exists in KiCad 9 CLI" section documenting:
    - pcb render, drc, export (gerbers, drill, pos, step, svg, etc.)
    - sch erc, export (bom, netlist, pdf, svg)
    - Renumbered remaining wishlist items (13 tools)
    - Updated "Existing Tools to Leverage" table
    - Clarified what gaps remain vs what's already solved
2025-12-31 Add comprehensive pin connections documentation
    - Complete 48-pin ISD3900FYI mapping with all nets
    - W25Q16JVSSIQ SPI flash 8-pin connections
    - KLJ-01304T speaker differential output
    - GL5528 LDR voltage divider circuit
    - Trigger input mux (LDR, button, pull-tab)
    - Net list summary and power budget
    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
2025-12-31 Fix ISD3900 SPI pin mapping (critical error)
    WRONG: Pins 13-16 (MISO/SCLK/SSB/MOSI) connected to flash
    RIGHT: Pins 2,3,28,29 (CSB/DI/DO/CLK) are external flash interface
    - Pin 2 (CSB) → U2./CS (flash chip select)
    - Pin 3 (DI) ← U2.DO (data from flash)
    - Pin 28 (DO) → U2.DI (data to flash)
    - Pin 29 (CLK) → U2.CLK (flash clock)
    Pins 13-16 are HOST SPI for MCU control, not used in standalone mode.
2025-12-31 Reorganize documentation structure
    Move docs to standard locations:
    - kicad/specs.md → docs/PRD.md
    - kicad/component-selection.md → docs/
    - kicad/schematic-design.md → docs/
    - currently-working.md → docs/status.md
    - kicad-agent-workflow-research.md → process/research/
    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
2025-12-31 Consolidate all docs under docs/, add PCB skills
    Documentation reorganization:
    - Moved process/ → docs/process/
    - All documentation now in single docs/ folder
    - Updated INDEX.md with correct paths
    Added project-level PCB skills:
    - pcb-master.md (orchestrator)
    - pcb-init.md (phase 0)
    - pcb-requirements.md (phase 1)
    - pcb-system-design.md (phase 2)
    - pcb-components.md (phase 3)
    - pcb-pin-allocation.md (phase 3.5)
    - pcb-schematic.md (phase 5)
    - pcb-layout.md (phase 7)
    - pcb-dfm.md (phase 8)
    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
2026-01-01 Clean up generated files and add JLCPCB integration
    - Remove generated images, gerbers, and production outputs from tracking
    - Add JLCPCB project database
    - Add PCB systems engineering documentation
    - Update KiCad schematic and PCB files
    [board.step, bom.csv, designators.csv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]
